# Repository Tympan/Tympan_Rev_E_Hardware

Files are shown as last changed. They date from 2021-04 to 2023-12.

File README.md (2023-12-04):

# Tympan Rev E Hardware Light
Repository for Tympan Rev E Light Electronics and case designs. This version of the Rev E is based on the Teensy 4.1 by PJRC and incorporates the Teensy 4.1 into our own design, as we did with the Tympan Rev D. This version is light in that it does not contain an on-board AIC, and is meant to be a PCB bridge between the Teensy 4.1 and the AIC Shield.

This is a work in progress.

## Check Back For Updates

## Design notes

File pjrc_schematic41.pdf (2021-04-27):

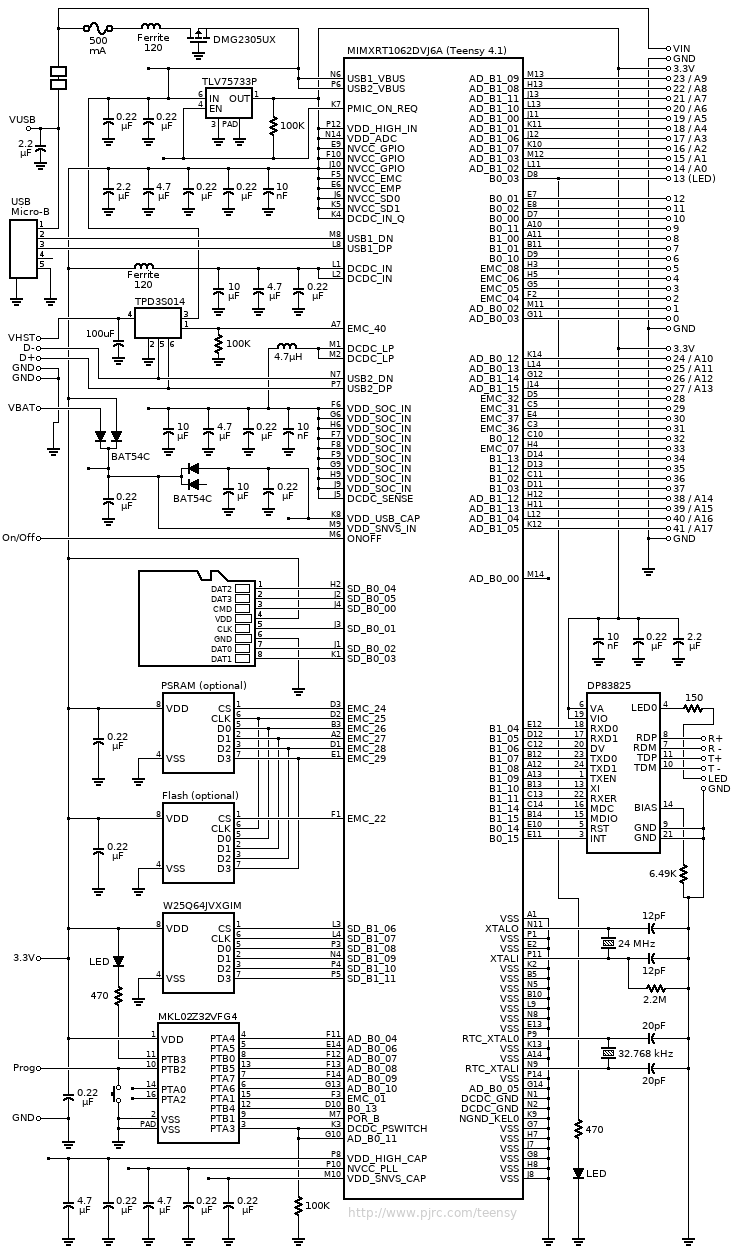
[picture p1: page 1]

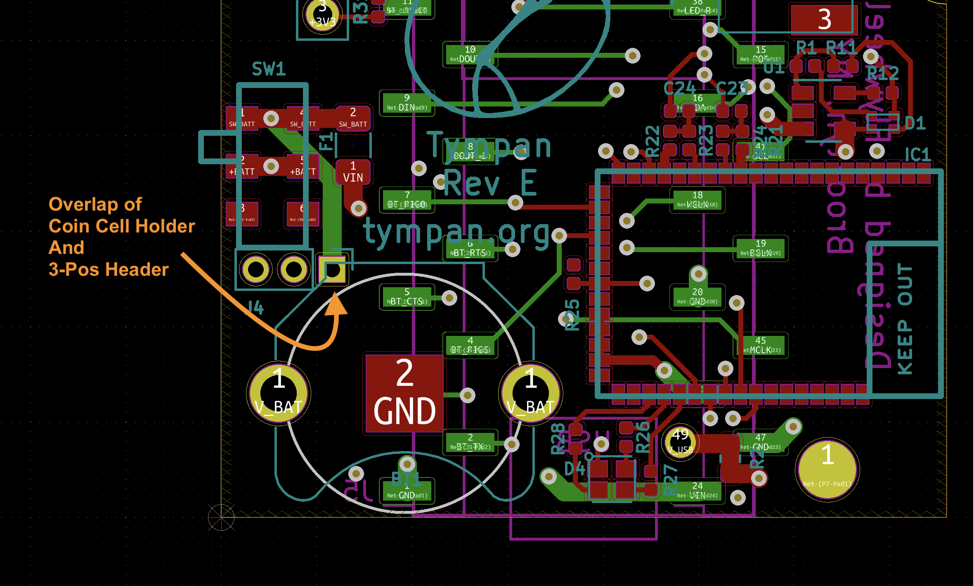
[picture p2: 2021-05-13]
assets/coin_cell_header_collision.png

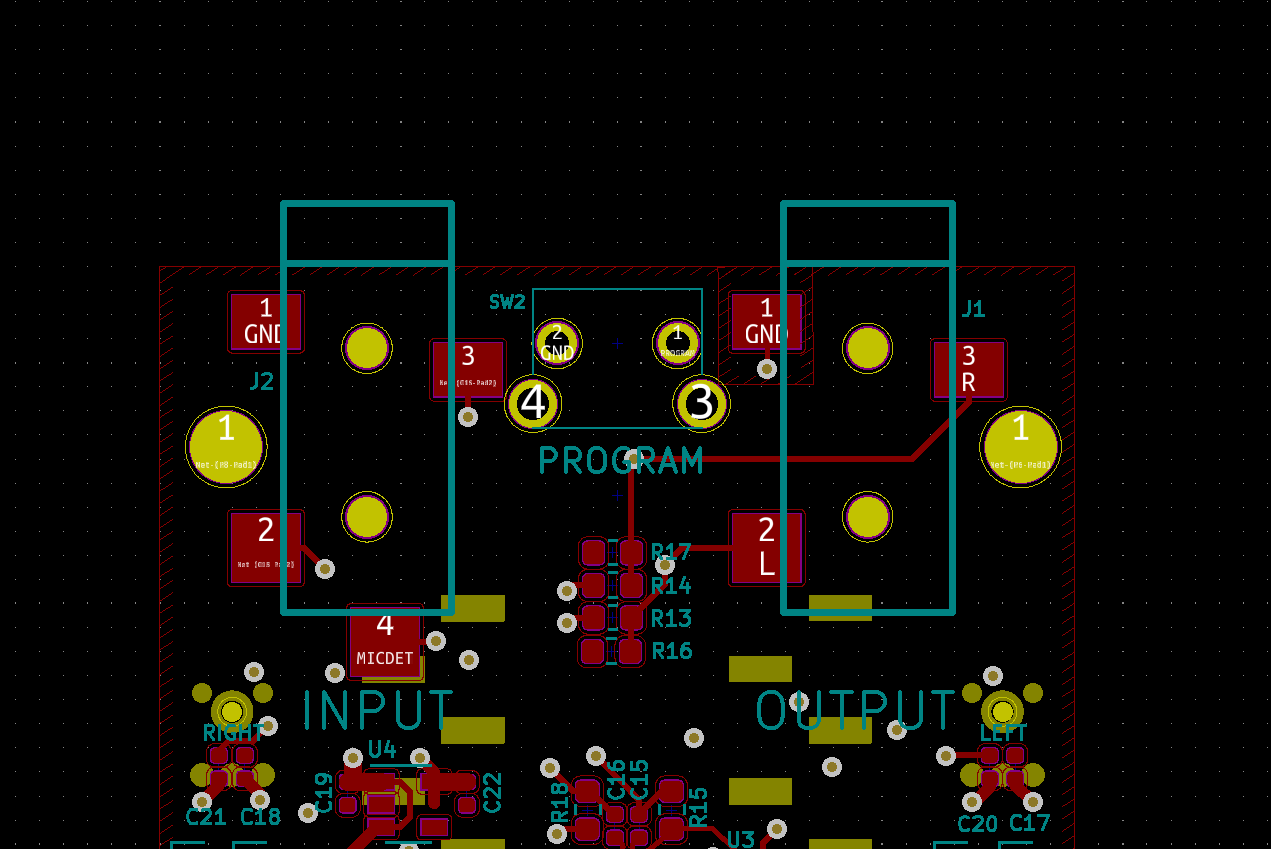
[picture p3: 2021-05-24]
assets/programButton.png

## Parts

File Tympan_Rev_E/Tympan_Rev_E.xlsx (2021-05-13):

Reference | Quantity | Value | Footprint
BT1 | 1 | Battery_Cell | Battery:BatteryHolder_Keystone_3001_1x12mm
BT2 | 1 | 4UCON-20519 | Solutions:4UCON-0217-20519
C7 C9 C14 | 3 | 10uF | Capacitor_SMD:C_0402_1005Metric
C1 C2 C3 C4 C5 C11 C15 C16 C23 C24 | 10 | 2.2uF | Capacitor_SMD:C_0402_1005Metric
C12 C19 C20 C21 C22 C26 | 6 | 1uF | Capacitor_SMD:C_0402_1005Metric
C6 C8 C10 C13 C17 C18 C25 | 7 | 0.1uF | Capacitor_SMD:C_0402_1005Metric
D1 | 1 | APHB1608SGNC | Tympan:ABHB1608S
D2 | 2 | LED AMBER | 1206
D3 |  | LED RED
D4 | 1 | Led_RGB_CA | Solutions:CLMVB-FKA-CFHEHLCBB7a363
F1 | 1 | FUSE | Capacitor_SMD:C_1206_3216Metric
IC1 | 1 | BC127 | Tympan:BC127
J1 | 1 | SJ-3523-SMT-TR | Tympan:SJ-3523-SMT-TR
J2 | 1 | SJ-3524-SMT-TR-PI | Tympan:SJ-3524-SMT-TR
J3 | 1 | Conn_01x03 | Connector_PinHeader_2.54mm:PinHeader_1x03_P2.54mm_Vertical
MIC1 MIC2 | 2 | SPM0687LR5H-1 | Tympan:SPM0687LR5H-1
P1 P2 P3 P4 | 4 | CONN_01X06 | Connector_PinHeader_2.54mm:PinHeader_1x06_P2.54mm_Vertical
R1 R11 R21 R22 | 4 | 1K | Resistor_SMD:R_0402_1005Metric
R12 | 1 | 2.2K | Resistor_SMD:R_0402_1005Metric
R13 R14 | 2 | 0R | Resistor_SMD:R_0603_1608Metric
R15 R18 | 2 | 2.2K | Resistor_SMD:R_0603_1608Metric
R19 R20 | 2 | 240R | Resistor_SMD:R_0402_1005Metric
R23 R24 R31 | 3 | 10K | Resistor_SMD:R_0402_1005Metric
R25 | 1 | 100K | Resistor_SMD:R_0402_1005Metric
R26 R27 R28 | 3 | 470R | Resistor_SMD:R_0402_1005Metric
R3 R4 R5 R6 R7 R8 R9 R10 | 8 | 33R | Resistor_SMD:R_0402_1005Metric
R29 R30 R32 R33 | 4 | 4K7 | Resistor_SMD:R_0402_1005Metric
RV1 | 1 | POT | Connector_PinHeader_2.54mm:PinHeader_1x03_P2.54mm_Vertical
SW1 | 1 | CL-SB-22A | Tympan:CL-SB-22A
U1 | 1 | MCP73831 | Package_TO_SOT_SMD:SOT-23-5
U2 | 1 | TLV320AIC3206IRSBT | Package_DFN_QFN:UQFN-40-1EP_5x5mm_P0.4mm_EP3.8x3.8mm
U3 | 1 | 74LVC1G66 | Package_TO_SOT_SMD:SOT-353_SC-70-5
U4 | 1 | LP5907MFX-1.8 | Package_TO_SOT_SMD:SOT-23-5
U6 | 1 | LC709203 | Tympan:WDFN8_3X4mm_0.65P

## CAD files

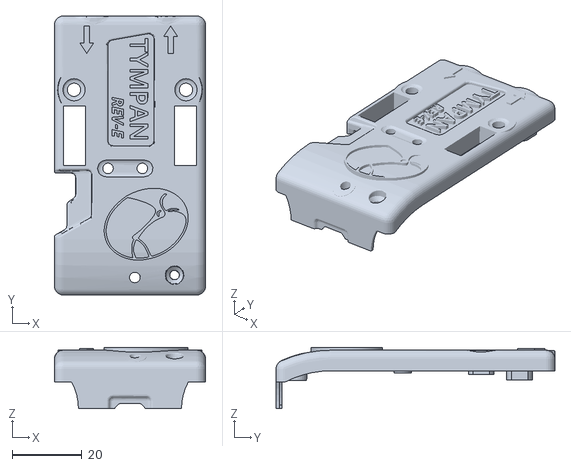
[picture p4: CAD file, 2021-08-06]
Enclosure/7-21 Tympan Rev E-2 Top.stl
43.2 x 79.8 x 17.5

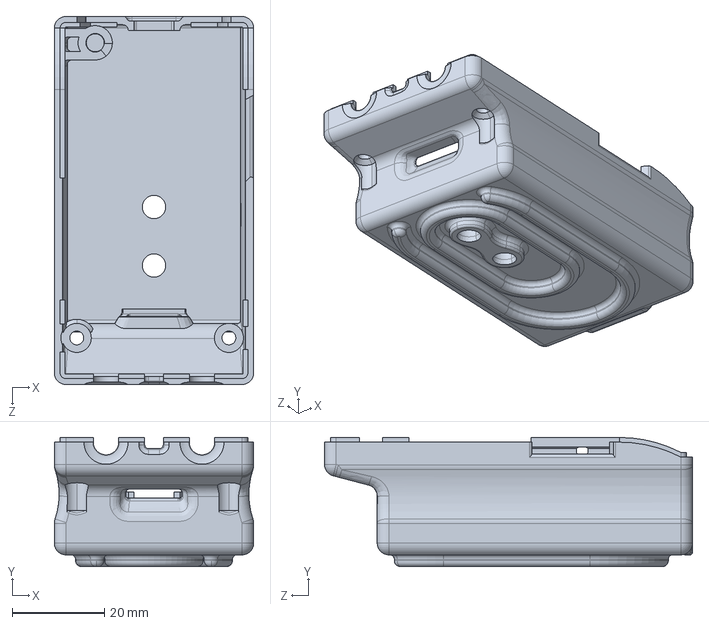
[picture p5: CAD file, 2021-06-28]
Enclosure/Exports/7146_Tympan_Rev-E2_Bottom_Case.STEP
43.2 x 28.0 x 79.8 mm

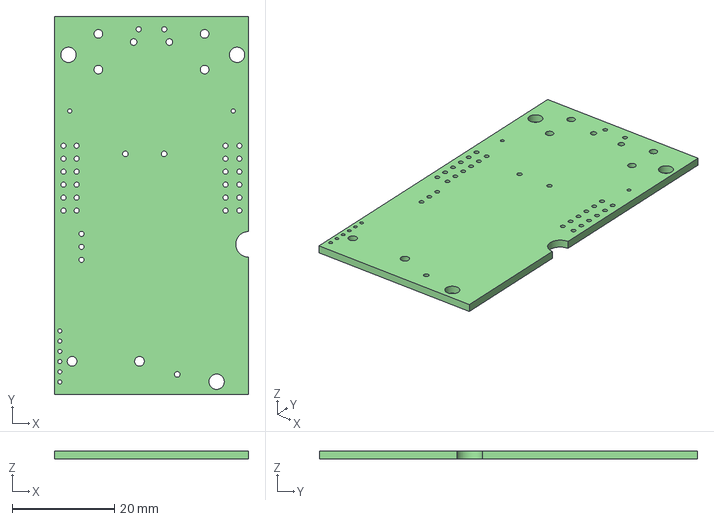
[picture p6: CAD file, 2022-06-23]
Tympan_Rev_E/Tympan_Rev_E.step
38.0 x 74.0 x 1.60 mm

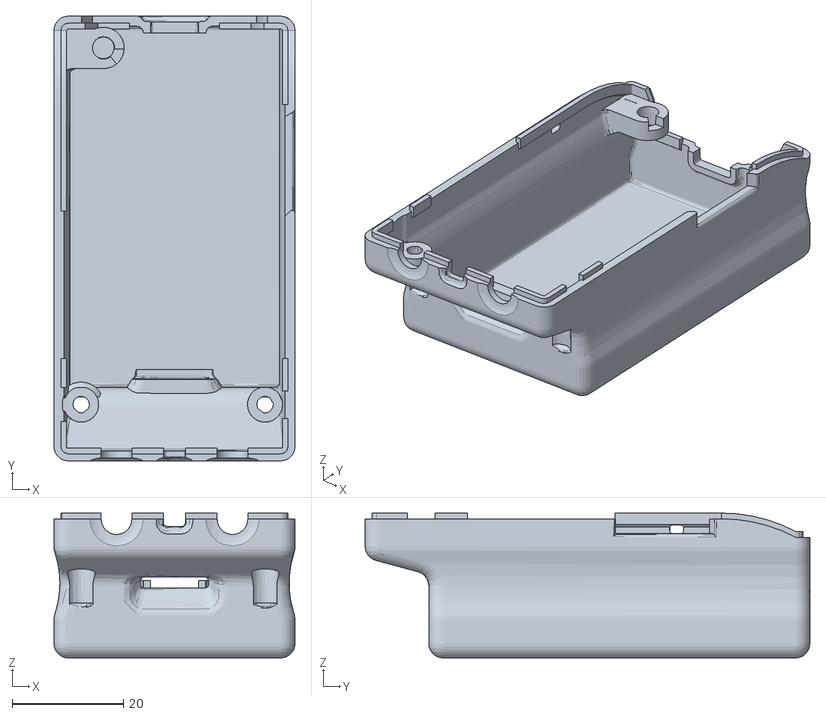
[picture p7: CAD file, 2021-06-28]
Enclosure/Exports/Tympan Rev E-2 BOTTOM_Flywheel_Mod.stl
43.2 x 79.8 x 26.0

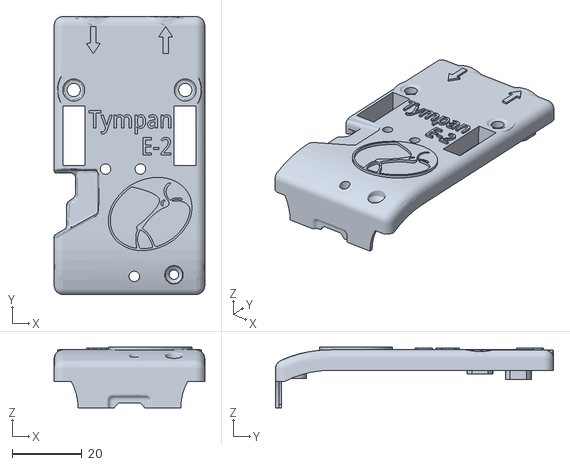
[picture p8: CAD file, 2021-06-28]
Enclosure/Exports/Tympan Rev E-2 TOP_Flywheel_Mod.stl
43.2 x 79.8 x 17.5

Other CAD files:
Enclosure/7-21 Tympan Rev E-2 Bottom.stl
Enclosure/Exports/7146_Tympan_Rev-E2_Top_Case.STEP
Enclosure/Exports/7146_Tympan_Rev-E2_Bottom_Case.stl
Enclosure/Exports/7146_Tympan_Rev-E2_Top_Case.stl

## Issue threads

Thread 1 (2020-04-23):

Identify all Teensy4 pins desired for I2S / Audio experiments

chipaudette, 2020-04-23:
There are several I2S buses on the Teensy4, each with their own clock and data pins.  Which of these pins should we break out and make available in the RevE hardware?

chipaudette, 2020-04-23:
@biomurph @erk1313

See, I do know how to use GitHub to make issues.  :)

chipaudette, 2020-04-23:
Apparently, they've done lots of development on multi-channel audio since I last checked.  They've got 8-channel I2S classes now.   It appears one can do up to 8-in / 2-out, or you can flip it around and get 2-in / 8-out.  That's pretty hot.

Here's one example, using 8 inputs.

https://github.com/PaulStoffregen/Audio/blob/master/examples/Analysis/PeakAndRMSMeter8Channel/PeakAndRMSMeter8Channel.ino

chipaudette, 2020-04-23:
Here are the forum links that I used as reference:

https://forum.pjrc.com/threads/57423-Teensy-4-0-I2S-without-Audio-Shield-and-flash-memory-question

https://forum.pjrc.com/threads/57167-Teensy-4-0-I2S-Support

https://forum.pjrc.com/threads/41371-Quad-channel-output-on-Teensy-3-6?p=230270#post230270

chipaudette, 2020-04-23:
OK, here are the I2S connections that are supported on the T4.

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

I'm not sure which get routed to the two AICs.  It looks like there can be several "right" answers, depending upon how the audio library software is configured.  Some experimentation will be needed.  This is why I'm hoping that the board provides some through-holes to allow me to jumper different Teensy pins to different I2S data lines to the Tympan's AIC and to the AIC shield.

chipaudette, 2020-04-23:
@biomurph, can you take a look at these pins and think about whether we can make all of them available to the hacker-user?

biomurph, 2020-04-23:
That'a great that the Teensy community pulled off 8 channel audio!
s u r r o u n d   s o u n d
I will look into what this means for the schematics that I already put together.

chipaudette, 2020-04-23:
FYI, in looking at the Teensy Audio Shield, it looks like the baseline 2-channel I2S pins are (not surprisingly) I2S Port #1 and employing Pins 7 and 8 for the actual data...so "OUT1A" and "IN1".  Fine.

Still looking at the Teensy Audio Shield, it looks like*
* The T4 Pin labeled "OUT1A" is actually **receiving** data from the audio shield
* The T4 Pin labeled "IN1" looks to be **sending** data to the audio shield

This is found purely by looking at Paul's diagrams and tables here: https://www.pjrc.com/store/teensy3_audio.html.  Perhaps I'm misinterpreting.

Why do they call it DIN/DOUT??? So confusing!  Why not MOSI and MISO??

biomurph, 2020-04-27:
I put up a spreadsheet with the Rev E pin assignments [here](https://docs.google.com/spreadsheets/d/1BYLmCkXKEUeF8b7aSnclLnglRlwAUCEZ10-2DhZgXo0/edit?usp=sharing).
Image of the spreadsheet below. I am able to fit in both of the I2S busses and only have to move a couple things around. Here are the moves and the potential issues

- Moved BT_CTS and BT_RTS. I assume these are software defined pins?
- Moved M_BIAS. This is software defined, so no problems there.

There's still a lot of flexibility for board layout and routing needs.

- The extra OUT1 pins are assigned to software defined functions in this draft, so they can be moved as needed
- I have not relocated the SPI bus pins, as this is a feature that we are not using so much.

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

chipaudette, 2020-04-27:
Regarding the BT_CTS and BT_RTS, I'm not sure that I've ever actually used these pins.  I'm not sure that I've ever used CTS and RTS (at least, not on-purpose) so I'm not even sure how to use them!

Looking in Tympan.h, where I define all the pins for the different versions of Tympan, the only BT pins that I see are:

'''
    BT_nReset = 34;  //PTE25, active LOW reset
    BT_REGEN = 31;  //must pull high to enable BC127
    BT_PIO0 = 56;   //hard reset for the BT module if HIGH at start.  Otherwise, outputs the connection state
    BT_PIO4 = 33;  //PTE24...actually it's BT_PIO5 ??? JM: YES, IT IS BT_PIO5!
'''

So, I guess that it's not a problem that BT_CTS and BT_RTS get moved.

Chip

chipaudette, 2020-04-27:
Regarding needing more I2C connections in order to feed all of my dreamed-about AICs, that's a good catch.  Seems like we'll need an I2C multiplexer.

https://www.adafruit.com/product/2717

Now it seems like this is kinda getting out of control, eh?  It seems like that if I want to do a proper 4-aic (ie 8 audio channel) demo, I really ought to design the board to do that, including all of the AICs.  I mean, with this RevE, what am I going to do...do flying leads off to all of the other AICs?!?  That sounds crazy.

So, maybe we should limit our scope with Rev E.  We should assume that we're going to talk with the on-board AIC the same way that Paul has the T4 talking to the Teensy Audio Shield (the new RevD version of the Teensy Audio shield).  It's the second Tympan AIC that I'm less sure about...

So, for the second Tympan AIC, we'll control it via the 2nd I2C bus, like with Tympan RevD.  The unknown is which I2S connections I want to route over to the headers for our shield.  So, I guess it's here that I need through holes for the various I2S lines that I specified above.  And then I need a few more through holes that let me mix-and-match those signals over to the headers that go up to the AIC shield.

Does that make sense?

Chip

chipaudette, 2020-04-27:
If we're super lucky, I might even be able to use my new T4.1 beta and do flying leads over to a pair of RevC boards.  Then, I could try Paul's example 4-channel code that has been extended for T4 (even though its documentation hasn't) and give it a try.  Through such a demonstration, I'd prove exactly which pins we want.

But, that'll take me a little time.  Tomorrow (being my "teleconference Tuesday")  is not going to be the day for that.

Chip

chipaudette, 2020-04-28:
After checking in on the forum regarding the I2S_quad class and its support for Teensy 4, I got the following response...

https://forum.pjrc.com/threads/58754-What-is-the-current-state-of-Audio-Library-support-for-the-Teensy-4-0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

So, maybe pins 6 and 8 for the two I2S input data lines (ie, data from the AICs to the Teensy) and maybe pins 7 and 32 for the two I2S output data lines (ie, data from the Teensy to the AICs).

I'm cross-referencing with the Teensy 4 pinout now...

Chip

chipaudette, 2020-04-28:
Looking at the [Teensy 4.0 pinout](https://www.pjrc.com/store/teensy40.html), specifically at the yellow colored pins flagged for "Digital Audio", I see:

Pin 6 = OUT1D
Pin 8 = IN1  (This is "DOUT" on the [Teensy Audio Shield RevD](https://www.pjrc.com/store/teensy3_audio.html))

Pin 7 = OUT1A  (This is "DIN" on the Teensy Audio Shield RevD)
Pin 32 (pad on bottom of T4) = OUT1B

So, the Pin 8 and Pin 7 are consistent with the Teensy Audio Shield (RevD), which is great.  In a quad setup, this suggests that these would be audio channels 1 and 2 (out of 4).  This suggests that the channels 3 and 4 would be on Pins 6 and 32.  If true, this would mean that the I2S_quad classes are exploiting the processor's ability to remap some of the I2S lines between inputs and outputs.  Cool.

With my beta Teensy 4.1, I should be able to prototype this using Teensy Audio Boards that I have on-hand.  I may get to try this tonight.

Chip
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
chipaudette, 2020-05-20:
Using this new test hardware....

I ran a quad-channel version of the tone sweep sketch.  It correctly generated audio out of the headphone jack on each of the two boards (independently).  So that's a success.  It proves that swapping pin 32 for pin 7 is the correct substitution.  Put that one in the bank.

However, when I try to acquire audio to bring in via the line-in / mic input, I can't get audio to come in via the 2nd audio board.  So, this calls into question the pin 6 for pin 7 swap.  In visually inspecting the modified board, however, I'm not sure that the mod was done correctly.  So, when I'm in the office again (Friday?), they'll take another cut at it.

chipaudette, 2020-05-28:
Under the assumption that we didn't modify the board as intended, we took a fresh Teensy Audio Board and did the modifications again.

Again, it can play audio out the headphone jack just fine, but it cannot record audio from the line-in jack.  :(

chipaudette, 2020-05-28:
I posted this issue to the Teensy forum:  https://forum.pjrc.com/threads/61123-Teensy-4-1-and-4-channel-audio-(AudioInputI2SQuad)?p=241457#post241457

biomurph, 2020-05-28:
I hope the power of the forum will come to our rescue!

Joel
~~~
Making the world safe for robots
www.biomurph.com

On Thu, May 28, 2020 at 4:23 PM Chip Audette <notifications@github.com>
wrote:

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

chipaudette, 2020-06-04:
The forum gave some debugging ideas.  And, Paul himself [jumped in](https://forum.pjrc.com/threads/61123-Teensy-4-1-and-4-channel-audio-(AudioInputI2SQuad)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) to demo that the system worked for him.

So, I brought the hardware back to the lab.  We probed pin6 and saw digital data.  Then, we disconnected our pin6 wire and did a flying lead direct to pin6.  The system worked.  Then we removed the flying lead and soldered our original wiring back in.  For some reason, it now works.

Conclusion: the Teensy4 support for quad audio works using pins 8+7 and pins 6+32.

I now have to decide what other pins, if any, I want broken out.

biomurph, 2020-06-04:
Sweet!
So those pins 8+7, 6+32 are the DIN DOUT pairs for coms with the AIC, correct?

chipaudette, 2020-06-17:
Yes, 8+7 is one set (the default set) and 6+32 is the second set (for the optional AIC).

As for which is DIN and which is DOUT, this is a long-standing problem of ours.  I'm looking at your google spreadsheet now.

chipaudette, 2020-06-17:
Looking at the RevD schematic, it looks like our "DIN" and "DOUT" are relative to the AIC.  So, in this convention:

* DIN for the 1st AIC = T3.6 Pin 22 = T4.x Pin 7
* DOUT for the 1st AIC = T3.6 Pin 13 = T4.x Pin 8

* DIN for the 2nd AIC = T3.6 Pin 15 = T4.x Pin 32
* DOUT for the 2nd AIC = T3.6 Pin 38 = T4.x Pin 6

I think that you've already accounted for the I2C and SPI signals moving pins on the T4.x vs the T3.6?

chipaudette, 2020-06-17:
Looking at your google spreadsheet a little bit, it looks like the Pin6 and Pin32 assignments will force you to move some of the existing functions.  Bummer, but we'll deal.  Hopefully there are pins that you can move them to!

chipaudette, 2020-06-17:
Is there more input that I need to provide here?

biomurph, 2020-06-18:
Thanks for chasing that down! I will see about re-juggling the pin assignments to fit the I2S and offer it up for review.

biomurph, 2020-08-03:
@chipaudette
Per your notes here, I have updated the schematics to reflect the correct DIN, DOUT, DIN_1, DOUT_1 pin connections.
The other pin connections that are flexible are in place and subject to change for ease of routing purposes.
Plan is to break out all of the unused pins, and also add the recommended memory chips on the bottom of the board.
Here's direct link to the [schematics](https://github.com/Tympan/Tympan_Rev_E_Hardware/blob/master/Tympan_Rev_E/Tympan_Rev_E_Schematic.pdf)
Couple of questions:

1. ON/OFF pin can be connected to a pull-down push button to manually turn off and then on the chip. Do we need it?

2. REV_TEST functionality. For Rev D, we used pin 44 tied to GND. Teensy 4.1 does not have a pin 44. I'm using pin 22 (no special reason). Should we connect 22 to GND as we did for rev D? Use another pin?

chipaudette, 2020-08-12:
I don't see a need for the "ON/OFF" button...but I'm not knowledgeable about it.  If there's not one on the T4.1, I guess that we don't need one.

For REV_TEST, using pin 22 seems fine enough to me.

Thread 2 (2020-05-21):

Increase capacity of the 3.3V power supply

chipaudette, 2020-05-21:
In my experience running 4 channels at high speed with SD writing, the system becomes unstable.  I believe that the power draw is too large for the existing regulator, given the voltage of the LiPo battery.

Recent current draw measurements suggest that we can pull 200-300 mA, which is nearing the max of the current [AP2210 regulator](https://www.diodes.com/assets/Datasheets/AP2210.pdf).  Specifically, if we were to pull 300 mA, the voltage drop would be 250-500 mV, which means that our battery would need to have a voltage of 3.55 to 3.85 V.  Given that the nominal voltage is 3.7V (though higher after immediate charge), that's a recipe for brown-out and for much reduced battery life.

Moving to the Teensy 4, where we can move to higher CPU speeds, we will likely increase this power consumption even more.  I think that we'll be regularly in the 300 mA range, with excursions higher.
 I think that we should consider bigger power supplies.

Looking at digikey, the nearest bigger regulator is the [AP2213, 500 mA](https://www.diodes.com/assets/Datasheets/AP2213.pdf).  What I see, however, is that the total capacity may be higher, but that the voltage drop is the same for a given current draw.  So, if our problem is that our battery voltage just isn't high enough for the regulator to deliver the required current, switching to the 2213 doesn't appear to solve the problem.

@biomurph, @eyuan-creare : does anyone know of a low-noise regulator (similar to the 2210) that has less voltage drop when in the 200-400 mA range?

biomurph, 2020-05-21:
I just did a quick look at Adafruit WiFi module ([HUZZAH ESP32](https://learn.adafruit.com/adafruit-huzzah32-esp32-feather/downloads?preview_token=0X3pzGCh9fm47-K5awpMrA) as those things are usually super power hungry and Adafruit is good at power supply design. They use the [AP2112](https://www.diodes.com/assets/Datasheets/AP2112.pdf), which has a high output current (600mA) and what seems like darn good drop out voltage. Not enough time right now to do a head-to-head comparison, but worth a look.

eyuan-creare, 2020-05-22:
Good thought Joel.  Never thought of looking at what other products use.  Here's a nice LDO, but it's expensive ($6).  Two package sizes:
[ADP7156ACPZ-3.3-R7](https://www.digikey.com/product-detail/en/analog-devices-inc/ADP7156ACPZ-3-3-R7/ADP7156ACPZ-3-3-R7CT-ND/5957834)
[ADP7156ARDZ-3.3-R7](https://www.digikey.com/product-detail/en/analog-devices-inc/ADP7156ARDZ-3-3-R7/ADP7156ARDZ-3-3-R7CT-ND/5957841)

Specs
* Dropout: 50-120mV
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

* PSSR: -80dB
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

eyuan-creare, 2020-05-22:
Noting the PSSR for the existing AP2210 regulator:
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

eyuan-creare, 2020-05-22:
If we are happy with 0.29V dropout, then there are some for $0.50 with 700mA output and low PSSR.
[NCP167 series](https://www.digikey.com/products/en/integrated-circuits-ics/pmic-voltage-regulators-linear/699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)

eyuan-creare, 2020-05-22:
AP2112 has a 0.25V dropout, which is nice.  PSSR is around 65dB:
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

And AP2213 only defines PSSR for 10mA, but it is around 60-70dB
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

 It has this note, which suggests that for good PSRR, Vin should be 1V higher than Vout.  Likely true for other LDOs as well.
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

eyuan-creare, 2020-05-22:
Nice reference on choosing LDO regulator specs from [Analog](https://www.analog.com/en/analog-dialogue/articles/understand-ldo-concepts.html)

eyuan-creare, 2020-05-26:
Alternatively, we could spec a buck boost converter for providing 5V to the BT module.  That would keep it from sagging the 3.3V bus when it sporadically draws current.

chipaudette, 2020-06-17:
Nice work, team!

For the AP2112, we have a working schematic from Adafruit and we have Adafruit's seal-of-approval.  That seals the deal for me.  Let's go with that.

chipaudette, 2020-07-06:
Adding a Buck-Boost option (as suggested earlier), for completeness.  Shouldn't be needed with a LiPo to support by 3.3V, but there is a certain appeal:

TPS6303x:  https://www.ti.com/lit/ds/symlink/tps63031.pdf

Let's stick with the AP2112 because of the adafruit documentation.

Chip

biomurph, 2020-08-03:
Moving to the Teensy 4.1 and reviving this topic.
The schematic for the 4.1 is [HERE](https://www.pjrc.com/teensy/schematic.html)
Paul is using the [TLV75733](https://www.ti.com/store/ti/en/p/product/?p=TLV75733PDRVR) Vreg.
The output current limit seems to be adequate. @eyuan-creare is the PSRR and drop out OK?

erk1313, 2020-08-03:
@Chip: @biomurph suggested the TLV75733, which is part of the Teensy 4.1 design.  It has a high output current (1A), a low dropout, and a decent PSSR.  The PSSR is less than our existing Rev-D regulator, but that's probably not important as we are not feeding it from a high-switching supply, nor have components that create high frequency noise.  I would say it's fine.

| IC | Max Current | Dropout @500mA | PSR @ 10kHz; 500mA | PSSR Plot |Link |
|----|----|----|----|----|----|
| AP2112 | 600mA | 250mV | 67dB |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|[datasheet](https://www.diodes.com/assets/Datasheets/AP2112.pdf)|
| TLV75733 | 1000mA | 175mV| 45dB | 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|[datasheet](https://www.ti.com/lit/ds/symlink/tlv757p.pdf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)

chipaudette, 2020-08-12:
Sounds good...let's go with the TLV75733.

Closed 2020-09-25.

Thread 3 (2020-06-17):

Design for T4.0 or T4.1?

chipaudette, 2020-06-17:
I believe that you had found solutions for the all those difficult-to-use pads on the T4.0, but why should we stick with the T4.0 form-factor when we could just switch to the T4.1 and use much-friendlier female 0.1" headers?

biomurph, 2020-06-18:
ooooooooh yeah!!
Life just got easier.

Looking at the specs, it is a nice beast! USB Host! Ethernet! Memory expansion!

I'm gonna get mine today!

biomurph, 2020-09-03:
@chipaudette I have the board laid out and routed.
It looks good to me, and I'd like to green light a prototype run.
Please take a look at the work and let me know what you think.

I have the Teensy mounted on the bottom of the board. Can do with mating headers, or can do by soldering SMT pins into the teensy 4.1 for low profile.

Same form factor as the Tympan Rev D, with breakouts, board size, mounting holes, volume knob, power switch, LEDs all in the same position (except for the charging LED...)
I plan to route a slot on the right of the board to allow the battery cable to snake to the back of the board.

biomurph, 2020-09-08:
@chipaudette
The board is ready to go! Please take a look at the schematics and let me know if you see anything that needs attention, otherwise I am prepared to green light this design and get the BOM ordered.

Closed 2021-06-10.

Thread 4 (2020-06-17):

Startup of BT Module

chipaudette, 2020-06-17:
@eyuan-creare and @biomurph ,

On RevD, we have the issue where sometimes the BT module doesn't start when the rest of the system starts.  The most obvious symptom is that the 3-color LED attached to the BT module never comes on.

We have talked about this.  But did we ever identify the specific circuit changes that we wanted to implement to try to make this problem better?  If so, we could try some here on Rev E.

Does anyone have any notes?

eyuan-creare, 2020-06-17:
Captured with the Rev-D issue: https://github.com/Tympan/Tympan_Rev_D_Hardware/issues/2
The BT Module datasheet provides an example circuit, I believe.  If not, let me know and I can dig up a blog post that went into more detail.

biomurph, 2020-06-18:
That RC circuit referenced is very easy to add.

A (maybe related) issue is one I've noticed, and would appreciate if someone could try to replicate it.
I'm attempting to turn the BC127 on and off by controlling the BT_nRESET (pin 34).
I'm using a pushbutton, but I'm sure that it could be toggled with a serial prompt.
The issue is that the BC127 does not always come out of reset when I try to turn it on. Maybe I'm holding the reset pin low for too long... It does wake up when I only reset for a short while (seconds) but if long(er) then it's no-go.
Maybe I'm doing it wrong, but my goal is to turn off the BT module when not in use, so that it will save power.

eyuan-creare, 2020-06-19:
Transferred the Rev-D issue to this repo.  Closing this so it is in one spot.  Refer to #5

Closed 2020-06-19.

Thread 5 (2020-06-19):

Intermittent power up fail on the BC127

biomurph, 2020-06-19:
Every so often at start up the BC127 LEDs don't flash, indicating that it has not booted up correctly. Since this is intermittent, it seems to be a result of the power supply. There is a related issue [here](https://forum.pjrc.com/threads/31688-chip-won-t-power-on-unless-I-wait-since-last-power-on). The recommendation from the BC127 datasheet is on page 26 of [this document](https://media.digikey.com/pdf/Data%20Sheets/Sierra%20Wireless%20PDFs/BC127_-HD_-EXT_TechSpec_4-9-17.pdf).

There's room on the board to add the RC circuit in the next hardware revision.

eyuan-creare, 2020-06-19:
Here is the boot sequence required by the BC127.  Note that VReg needs pulled high 5ms after VBat goes high.
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

[Datasheet](https://media.digikey.com/pdf/Data%20Sheets/Sierra%20Wireless%20PDFs/BC127_-HD_-EXT_TechSpec_4-9-17.pdf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)

Here is what the existing code does under Tympan.h.  I believe this sequence needs updated. I also recommend adding error checking, where the BT127 is reset if there is a problem (BT_nReset = LOW for >20ms).  @chipaudette let me know if you want me to start a feature branch to try this out.

@biomurph: The device should power on with BT_REGEN = LOW and BT_nRESET = HIGH.  Can you change the pull-down/up resistors so it starts this way?

**Existing boot sequence**
1. Upon setupPins(), set BT_REGEN = HIGH; wait 10ms
2. Set BT_REGEN = LOW
3. Set BT_nReset = LOW; wait 10ms
4. Set BT_nReset = HIGH
5. Configure BT_PIO0, as input

```
	//get the comm pins and setup the regen and reset pins
	USB_Serial = pins.getUSBSerial();
	BT_Serial = pins.getBTSerial();
	if (pins.BT_REGEN != NOT_A_FEATURE) {
		pinMode(pins.BT_REGEN,OUTPUT);digitalWrite(pins.BT_REGEN,HIGH); //pull high for normal operation
		delay(10);  digitalWrite(pins.BT_REGEN,LOW); //hold at least 5 msec, then return low

	}
	if (pins.BT_nReset != NOT_A_FEATURE) {
		pinMode(pins.BT_nReset,OUTPUT);
		digitalWrite(pins.BT_nReset,LOW);delay(10); //reset the device
		digitalWrite(pins.BT_nReset,HIGH);  //normal operation.
	}
	if (pins.BT_PIO0 != NOT_A_FEATURE) {
		pinMode(pins.BT_PIO0,INPUT);
	}

	forceBTtoDataMode(true);
```
As of commit:  b927b227a25902c28c43c8ed1745633a7fbc59a0

**Recommended boot sequence:**
1. Upon setupPins(), configure BT_REGEN as input with pull-down, and BT_nReset with pull-up (or just rely on the external resistors to do this);
2. Set BT_REGEN = LOW; set BT_nReset = HIGH
3. Wait 5ms; set BT_REGEN  = HIGH
4. Test communication to BC127.  If it fails set BT_nReset = LOW for >20ms, then begin boot process again.

eyuan-creare, 2020-06-19:
I would also recommend putting a scope on the BC127's VCHG during the boot up process.  Look for it to dip below 3.1V.  This pin is what initiates the boot sequence. This measurement will help set what the filter should be.   It should be easy to tack on their recommended RC and take a measurement.  This should be tested to see how low the V-Bus can go without causing a dip that restarts the BC127, during bootup and communication.  This will help inform whether the buck boost is sufficient and where we should set our brown out point (if that's incorporated into the next design).
@chipaudette : Let me know if you would like me to tackle this.

eyuan-creare, 2020-06-19:
Quick note... Attached is the most recent technical manual for the BC127
[41110693 AirPrime BC127 Product Technical Specification r2.pdf](https://github.com/Tympan/Tympan_Rev_E_Hardware/files/4805536/41110693.AirPrime.BC127.Product.Technical.Specification.r2.pdf)

Here are the reset conditions we are looking for.  Note: you can reset, or power down the BC127 depending on how long you hold it LOW.
```
The AirPrime BC127 can be reset intentionally by two methods:
· Hardware reset via RST# pin
· Reset—Pull the RST# low for > 5 ms to reset the module.
· **Power down—Pull RST# low for > 2.4 s** to power down. A rising edge on VCHG
or VREGEN is required to restart the module.
· Software reset via AT command—Send the AT command RESET over the UART
interface to reset the module.
```

biomurph, 2020-06-19:
@eyuan-creare
I have the VREGEN pin pulled low in the hardware.
BT_nRESET is not pulled anywhere.

I will try the  latest notes on toggling the VREGEN. Good to know that the thing will power down after 2 seconds! That's convenient!

I will also watch the VCHG and compare notes.

biomurph, 2020-09-08:
I have the reset pin for the BC127 pulled HIGH as per your suggestion.

eyuan-creare, 2021-01-22:
@biomurph Did we address this in the design of the Rev-E, or were you considering a change in the firmware?  I don't remember what we settled on for a course of action.

biomurph, 2021-01-23:
On the Rev E, I have the BT_nRESET (RST#) pulled up with a 10K.
The Rev D does not have this pullup installed.

Both Rev E and Rev D have pull down resistors on the VREGEN pins.
This should allow for the Rev E to power up with pins pulled in the right directions.
The Rev D, however, would need some software to manipulate the RST# pin correctly.3

eyuan-creare, 2021-01-23:
Great! I'll take a look at implementing the change in firmware.

eyuan-creare, 2021-08-03:
@chipaudette It looks like the boot sequence has been corrected. I think we can close this out.

The one caveat is that we are not filtering the power supply input to VCHG.  This is the kind of thing that could cause intermitted behavior.
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

--short version of existing firmware booting up the BC127--
https://github.com/Tympan/Tympan_Library/blob/0247190d9da8d58e457f77e4b671b1f5fa128797/src/Tympan.cpp#L41

```
(Note: BT_nRESET is pulled high)
pinMode(pins.BT_REGEN,OUTPUT);digitalWrite(pins.BT_REGEN, LOW);
delay(10);
digitalWrite(pins.BT_REGEN,HIGH); //pull high for normal operation

delay(100);
digitalWrite(pins.BT_REGEN,LOW); //then return low

pinMode(pins.BT_nReset,OUTPUT);
digitalWrite(pins.BT_nReset,LOW);

delay(50);
digitalWrite(pins.BT_nReset,HIGH);  //normal operation.
```

eyuan-creare, 2021-08-03:
@chipaudette Perhaps I stumbled on something...

VREGEN not only is critical in the boot process, but it is used to put the BC127 in discoverable mode.  In the current firmware, VREGEN is pulled high for 10ms to put in indiscoverable mode.  However, Melody 7 states that a "short" press is 50ms, whereas we only pull it high for 10ms.  Also, we pull the nRESET pin low then high after this short press of VREGEN.  So perhaps this timing is preventing the BT module from being placed in discoverable mode?

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

 In a previous Tympan commit, VREGEN is brought high for 10ms then brought low.
```
if (pins.BT_REGEN != NOT_A_FEATURE) {
		pinMode(pins.BT_REGEN,OUTPUT);digitalWrite(pins.BT_REGEN,HIGH); //pull high for normal operation
		delay(10);  digitalWrite(pins.BT_REGEN,LOW); //hold at least 5 msec, then return low
```

eyuan-creare, 2021-08-03:
@chipaudette Also note the difference between Melody 7(above) and Melody 5 (below).  The duration for a short press changed from <999ms to 50ms (probably to provide debouncing as their dev board uses a momentary switch).   Also, note that a long press has a different function.

[_Melody 5.0 Rev-D_
](https://cdn.sparkfun.com/datasheets/Wireless/Bluetooth/Melody_5.0_Manual-RevD-RC10-Release.pdf)

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

eyuan-creare, 2021-08-03:
@chipaudette: so while the Medody5 boots up as a discoverable device (under default settings)...
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

-----
Melody 7 states that it is **not discoverable on bootup.**
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

chipaudette, 2021-08-03:
@eyuan-creare  thanks for the additional research on the startup process and on the GPIO.

Two observations that would be helpful for you to comment on:

* The word "discoverable" is only meaningful for making BT Classic connections, not BLE.  In your discussion of short vs long pulses and their effect on the discoverable mode, do you expect it to affect my BLE problems or only the BT classic (ie BT Audio) problems?

* For the short/long pulse discussion, the module has two GPIO control modes: (1) GPIO control "on" and (2) the badly-named GPIO control "off".  [In truth, both modes still respond to the GPIO pins, they just respond in different ways.]  Do your comments have to do with mode "on" or mode "off" or is it some GPIO mode specific to just the startup process?

Chip

chipaudette, 2021-08-17:
@eyuan-creare In your comments above, you suggested that we have VREGEN be held low instead of our previous pattern of holding it high.  I've now explored this.

On RevE with V7.3 HD firmware, I switched the code to keep holding the pin HIGH.  There's no obvious difference in behavior either way.  I command BT Classic behavior ("connectable" and "discoverable") through direct serial commands, as you suggested.  The system seems fine...but, again, it's not obviously better either way.  My conclusion: Whenever V7 firmware is specified, I have Tympan.h hold the pin HIGH forever, per your recommendation.

On RevD with V5.5 firmware, when I switched the code to keep holding VREGEN high, the module shuts off after ~2 seconds.  Obviously, this is bad.  My conclusion: Whenever V5 firmware is specified, I have Tympan.h return to the original behavior of staying HIGH for 100 msec and then switching LOW and staying LOW forever.

eyuan-creare, 2021-08-18:
>>On RevD with V5.5 firmware, when I switched the code to keep holding VREGEN high, >>the module shuts off after ~2 seconds.

Yes that is expected behavior.  It is supposed to SET CLASSIC_ROLE=1, SET AUTOCONN=1, then reset.  I assume those are non-volatile and when it boots up again it should be held high.  We might want to revert a Tympan to default settings if we think a  "new" Tympan might act differently.

Otherwise I can close this out.  The last remaining question is  whether there is noise on the VBAT or VCHG supply lines that could cause an issue during startup.

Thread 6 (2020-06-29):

Add ability to disconnect the battery for shipping

eyuan-creare, 2020-06-29:
For federal regulations for shipping lithium batteries, refer to [49 CFR 173.185(e)](https://www.phmsa.dot.gov/lithiumbatteries).  Also look into regulations from UPS and FedEx.

* Here is a [reference design for shipping Li-Ion batteries from TI](https://www.ti.com/lit/an/slva821/slva821.pdf?ts=1593441515767) based on a momentary push button and a load switch:
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.  It is also mentioned [here](https://e2e.ti.com/blogs_/archives/b/fullycharged/archive/2016/12/27/don-t-let-your-battery-drain-on-the-shelf-use-ship-mode).

* Some charger ICs also have ship mode, such as the [LTC4071 ](https://www.analog.com/media/en/technical-documentation/product-selector-card/2PB_4071.pdf).  This IC disconnects the battery when VBat drops below a threshold voltage.  (This provides the added benefit of handling brownouts.)

* A battery management IC ([PF1550](https://www.nxp.com/docs/en/data-sheet/PF1550.pdf)) that enters ship mode via I2C, and exits ship mode when a charging voltage is present

* Another battery charger with ship mode ([STBC02](https://www.st.com/resource/en/datasheet/stbc02.pdf))

* Another charger with ship mode: [DA9070](https://www.dialog-semiconductor.com/sites/default/files/da9070_final_datasheet.pdf).  This can enter ship mode via I2C (delaying the battery disconnect until after power if removed).  Exits ship mode when input power is restored.

* Another charger with ship mode [ISL9241](https://www.renesas.com/us/en/doc/datasheet/isl9241.pdf): Enter ship mode via register.  Exit ship mode by connecting power.

eyuan-creare, 2020-06-29:
* If the battery was a button-top, then you could insert a small strip of plastic as the disconnect.
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

eyuan-creare, 2020-06-29:
@chipaudette We could either replace the battery charger IC or add a load switch with ship mode.  Ideally, the design would not require a momentary on/off button.

If you like these option, I can mock up a design to pass by Ray.  I like the fact that there are reference designs we can point to.

biomurph, 2020-08-03:
@eyuan-creare I"m not sure if we need this kind of feature. We ship with a low capacity LiPo (500mAh) and I have found that if you are shipping them contained in equipment. Check out the end of page 4 on this [doc](https://www.ups.com/assets/resources/media/en_US/pack_ship_batteries.pdf). I don't think that we need to worry about Tympan due to the small battery size. Once you get into bigger battery capacity, that's when there may be question, but it seems the cutoff is pretty clear.

(unsure why I'm just seeing this, will check my settings)

erk1313, 2020-08-03:
@biomurph There's a whole range of regulations for shipping Li-ion batteries.  I have a summary I can share at some later point.
 If it weren't for the fact that we qualify as a low-production prototype, we would require UN38.1 testing for the completed assembly.  I'll be reviewing how Creare interprets these regulations with Creare's safety person in August and will check back then.  Their initial ruling was that a physical disconnect was required, but I think that is too conservative a ruling.

biomurph, 2020-08-03:
Sounds good, @eyuan-creare
My research has only gone as deep as UPS and DHL.

eyuan-creare, 2020-09-08:
After a review by Creare's safety team, the Rev-D design was deemed safe for shipping with the battery connected, with these three design changes:
* Place the fuse immediately after the battery
* Move the power switch before the voltage regulators

Notes contained on networked folder: \\OLYMPUS\Projects\7146-Cool-Aid\Technical Work\Design\2020-0710_Shipping Lithium Batteries

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

biomurph, 2020-09-08:
@erk1313
I can make those changes to the Rev E prototype design.

chipaudette, 2020-09-25:
@biomurph
Was this change fully implemented in Rev E?

Looking at the current RevE schem, I think that I see that the switch has been moved, but I don't think that the fuze is as early in the circuit as is shown here in the figure above.  It's immediately after the battery in the figure above, but it appears to be after the switch in the current RevE schem...

biomurph, 2020-09-29:
@chipaudette Changes done on my local. Will push to repo.

biomurph, 2020-09-29:
Just for the sake of clarity on this. The resoning we had in the beginning to arrange the power supply this way was to make sure that the RTC [V-BAT] was powered by the 3.3V. We gave users the option to add their own external power for the V-BAT. In order to do this, when the Tympan D was 'off', there was power going to the RTC only, so the 3.3V reg was running to do that when the switch was 'off'. In this new version, we are adding a coin cell to power the RTC, so we don't need to run the LiPo to do that work. That's why in previous the switch was after the Vreg.

Closed 2020-09-29.

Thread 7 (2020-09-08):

Fuel Gauge for Battery Level

eyuan-creare, 2020-09-08:
Add a fuel gauge (or spec a charging IC with that feature) to report the estimated battery level of the device.  This will allow the Tympan to close an SD recording before a power failure.  Note that Lithium batteries cannot rely on voltage to determine charge level.

@chipaudette : is this a nice-to-have feature or a must?

biomurph, 2020-09-09:
Here is a candidate for fuel gauge
https://www.mouser.com/datasheet/2/308/LC709203F_D-1810548.pdf

eyuan-creare, 2020-09-09:
Thanks for checking into these.  I've never used one of these chips before.  I see that it uses a special technique that doesn't use a sense resistor, but it looks like it relies on a thermistor.  Are there other reliable methods of measuring battery capacity?  I simply ask because it adds another component to the battery.
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

chipaudette, 2020-09-09:
Did we really talk about doing this for Rev E, or is it for the MIT hardware?

chipaudette, 2020-09-09:
@biomurph, that's the same IC as used in the recently-advertised Adafruit board, right?

https://www.adafruit.com/product/4712

eyuan-creare, 2020-09-09:
Looks like Adafruit is using it without a thermistor, so they forgo temperature compensation.

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

@chipaudette Yes, we talked about it in the context of the Dosimeter.  We can shelve this if not needed.

biomurph, 2020-09-09:
@chipaudette Yes! it does look like Adafruit is using the same IC!
Funny, I did not even check to see if there was one broken out by the SparkFruit people.

@eyuan-creare I selected the LC709203 because it does not require an external current sense resistor, and also noticed that it can be used with or without thermistor temperature measurement.
It seems to be the easiest to implement, and since we are not doing anything that is high current, or really stressing the battery in any way, I thought that the temperature measurement would be optional. Do you guys feel that it is something that we should look into?

If you're interested in playing around with this IC in the Tympan Library, I can add it into the Tympan Rev D spec and we can drive it around a bit?

chipaudette, 2020-09-25:
I'm interested in this, but I'm more interested in getting Rev E built for the first time.  So, let's not do this (yet) for Rev E.

biomurph, 2020-09-29:
@chipaudette There is room for it, and I can route it in but leave it unpopulated for now. How does that sound?

biomurph, 2020-09-29:
I added it into the layout, and we can decide to populate it or not. Super easy.

Closed 2020-09-29.

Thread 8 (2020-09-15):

Typo in project description

justinclift, 2020-09-15:
Noticed a cut-n-paste typo in the project description, and figured it's probably useful to mention:

```
Repository for Tympan Rev D Electronics and case designs
```

"Rev D" → "Rev E"

:wink:

chipaudette, 2020-09-25:
Looks like it's been fixed!  Thanks!

justinclift, 2020-09-25:
Looking at the project description again just now... er... it's still saying "Rev D"?

Can screenshot it, if we're looking at different pieces and confusing each other. :grin:

Closed 2020-09-25.

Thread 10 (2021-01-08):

Bring Teensy USB signal up to Tympan (for power and programming)

eyuan-creare, 2021-01-08:
To expose the SD card slot in the enclosure, one _possibility_ is sliding the Teensy forward. However this would hide the micro USB port.  Depending on complexity, we may want to bring up the USB signal to the Tympan to relocate a port there.  On the plus side, this would allow us to use a USB-C connector.

Here’s the pins labeled D- D+ on the side opposite of the Teensy 4.1.  I outlined the traces on that side of the board.

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

I flipped that trace to match it up with the other side.  That should correspond to the fingers on the micro USB connectors: D- (2) and D+ (3).  I'll pint this out when I get my hands on a Teensy 4.1 today.

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

@biomurph, @chipaudette  Got any ideas for how we could bring the USB signal up?  Looks like it is 0.1" spacing.  Would a header fit these pads?

eyuan-creare, 2021-01-14:
I tried soldering a header (0.1in pitch) to the USB D+ D- pads, but failed and lifted up a pad.  If the Teensy is first soldered to the Tympan, then perhaps there's low risk of lifting the pad.

@biomurph What are your thoughts?  Do you think soldering a header to these pads is feasible, or would you suggest wire leads?
- We could also do pogo pins (if their height was short).  They would likely be fine under vibration, as their spring force can be rather high.  But there is a possibility of corrosion over time.

biomurph, 2021-01-14:
It looks like the solder pads are 0.1" spacing?
If so, that makes it easier to cope with.
Then the issue becomes finding room to mount the USB C...

What about using Occam's USB converter?
https://www.wish.com/product/5e1e787f93907f0566eb2d2d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
Might this be long enough to make the distance?

eyuan-creare, 2021-01-14:
@biomurph The adapter is a great idea and converts it to USB-C.   I'm a little sketched out by using an extension, but that may be less sketchy than adding headers/pogo pin/leads to the USB pads.  They are 0.1" spacing.  Would you like to try experimenting on one of the Teensy's you have designated for us?  Even if you lift the pad, it shouldn't effect the USB connection.  I think that pad is just a test point for them to program the device (just a guess).

I'll order that Amazon adapter in and take a look at how rigidly it is held.

biomurph, 2021-01-14:
@eyuan-creare I will take a look at it. I am hesitant to use pogo pins, as they present their own mechanical issues, but they may be the best answer if we do our own connector. I can see that it will be difficult to get the solder points done in situ with the boards so close together and the USB C mounted likely right near there, so I would think that the pogos, if they are available at the right length, might be our best bet.

I'm looking at the layout and there seems to be room to put SMT pads or maybe through holes in the area where they might need to land.

Another issue with 'sliding the teensy' is that the pads for the Teensy may be crashing against the audio jack mechanical mount holes??

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

eyuan-creare, 2021-04-12:
The USB extension looks a little sketchy.  Too much leverage to pop the USB connector off.<br>
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

eyuan-creare, 2021-04-14:
@biomurph: Chip thinks the risks of either approach outweigh the benefits of exposing the SD card.  Let's abort this request.

Closed 2021-04-14.

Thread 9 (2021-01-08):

Bring Teensy reset button up to the Tympan

eyuan-creare, 2021-01-08:
In the existing enclosure, the battery obscures the reset button.  If we brought the reset signal up to the Tympan, then we could place a second reset button in a better location.  Likely, this would be a "side-press" button, but that is TBD.

- Existing enclosure:

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

- Teensy 4.1 Schematic showing the PROGO trace from the reset button:
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

- Teensy 4.1 PCB showing the trace from the PROGO pin to the Reset Button.  @chipaudette confirmed that this thru hole pin transitions LOW when the reset button is pressed

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

eyuan-creare, 2021-01-08:
@biomurph looked into where the pin would fall:

Here is about the location of the pad that we would need to place for it.
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

The good news is that the pad for the pin next to it (pin 30) is not in the way.
Also, there's enough room to either place a thru-hole, with a bunch of parts/trace juggling, or placement of a single SMT pad, with less parts/trace juggling.

There's also the option of flying a lead from the T 4.1 to the Tympan..

eyuan-creare, 2021-05-17:
@biomurph suggested placing a momentary pushbutton (TL6340AF160Q) between the audio jacks:

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

This should work fine, though it is a tiny switch.  The button is 1/32" tall. @chipaudette if you fine using a paper clip, I can put a guide hole in.  If you would like a feature on the case with a cantilevered tab, then we should go bigger.

biomurph, 2021-05-17:
possible candidate switches
https://www.mouser.com/datasheet/2/910/909_2894_2893_DTSA-6-1571568.pdf
The DTSA-6 drawing will fit and it is a decent size. There are tons of them.

eyuan-creare, 2021-05-17:
Goldilocks says... that switch is just too big!  It does fit, within the height of the stock headers but let me see it there is an alternative.

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

eyuan-creare, 2021-05-17:
@biomurph What do you think of this switch? (faked up CAD model).  It still feels a bit big but there is not much out there for RA switches.
- APEM MJTP1117 ($.48 [Digikey](https://www.digikey.com/en/products/detail/apem-inc/MJTP1117/1795496)) SPST- NO
<br>
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
<br>
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

biomurph, 2021-05-17:
Works great! Im down to use it.
You have it overhanging the edge of the PCB. Is that how you want to?

eyuan-creare, 2021-05-17:
@biomurph yes, please have the button overhang. Thanks!

biomurph, 2021-05-21:
I placed the MJTP-117 push button between the audio jacks

chipaudette, 2021-06-10:
@eyuan-creare , is this done?  can we close this?

Closed 2021-06-10.

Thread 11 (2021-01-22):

Data/Clock Labels for PDM Mic are switched on the board and schematic

eyuan-creare, 2021-01-22:
Please refer to Tympan Rev-D issue and confirm that this applies to the Rev-E as well: https://github.com/Tympan/Tympan_Rev_D_Hardware/issues/5

biomurph, 2021-01-23:
Confirmed that this issue did persist from Rev D to Rev E.
Made the changes and pushed to fix this issue.

Closed 2021-01-23.

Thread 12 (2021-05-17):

Add Thru Holes for Reuse of GPIO lines to RGB LED

eyuan-creare, 2021-05-17:
@biomurph : *if there is space*, it would be nice to break out the GPIO going to the RGB LED.  I'm thinking (3) thru holes spaced 0.1in apart. But only if you have space.

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

biomurph, 2021-05-17:
I will see. What is the reason for this breakout?

eyuan-creare, 2021-05-17:
For additional I/O.  It's not critical but if you have space for it, we've run out of GPIO in the past when we are using up the available pins for I2C, PDM, etc...

biomurph, 2021-05-17:
Ah, those pins come from the BC127. If you want more Teensy pins, that's a different thing

eyuan-creare, 2021-05-18:
Ah.  You're right.  I'm glad you asked about the why.  Well, if there is room to put 2-pin thru holes next to LED_A & LED_R, that would work as well.  And if not, we'll close this.

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

biomurph, 2021-05-18:
I put in two breakout GPIOs on the 2mm header at the bottom left.

Pin 34 and 35 are also UART 8 TX and RX

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

eyuan-creare, 2021-05-18:
Thanks for correcting me.  For some reason, thought we were using 0.1in spacing.

biomurph, 2021-05-18:
Well, we are using 0.1" for the breakout headers that the shield plugs into. the 2mm header was what would fit to make the RTC battery power on Rev D. That 2mm header row has now grown a few pins.

eyuan-creare, 2021-05-18:
Ah.. now I understand.

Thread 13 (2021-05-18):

Size RTC battery

eyuan-creare, 2021-05-18:
The RTC on the Teensy4.1 is integrated on the micro, which the datasheet says requires (20uA).
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

However the Teensy 3.6 was measured to draw 2uA, while the datasheet suggests 1uA.  Paul believed this additional current was diode leakage, so let's assume 21uA for the Teensy 4.1:
https://forum.pjrc.com/threads/45399-Shutdown-RTC-current

The existing [CR1220](https://www.digikey.com/en/products/detail/panasonic-bsg/CR1220/269740) is 35mAH, which provides a life expectancy of 66days:
- 35mA-hr*3V/3.3V*20uA*1day/24hr = 66 days

Not very impressive.  But I believe this would only be the case if the main lithium battery was depleted.

~~~
We could go down to two 6mm coin cells (2*1.5V * 20mAh), but there were no holders for two stacked 6mm coin cells.

eyuan-creare, 2021-05-18:
@chipaudette Reducing the coin cell appears to be a dead end.  I have not measured actual Teensy 4.1 current draw, but from the spec sheet, the CR1220 should last ~66days.

Closed 2021-05-18.

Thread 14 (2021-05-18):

Room for QUIIC?

chipaudette, 2021-05-18:
@biomurph There's no room for a QUIIC connector anywhere is there?  (I do love QUIIC)

biomurph, 2021-05-19:
It looks like a Qiic connector could fit under the volume knob... lousy location...
Mayby I could throw one in above MIC1 next to the speaker jack?

biomurph, 2021-05-19:
Here's a shot of the Qwiic location that is the easiest to do.
It's at the front of the board, on the bottom layer, underneath the PROGRAM pushbutton between the audio jacks.

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

biomurph, 2021-05-21:
Placec Qwiic connector on the bottom near the battery connector. It fits!

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

Closed 2021-06-10.

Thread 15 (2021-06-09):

Decide Direction for the Rev-E Enclosure

eyuan-creare, 2021-06-09:
- [x] Determine what the stackup height is.  @biomurph is planning to solder the Teensy to the Tympan
- [x]  How do users access the SD slot?

_Here is the existing enclosure for the Rev-E with AIC shield_
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

- [ ] What plastic do we use?  The white plastic from Rev-D has shown yellowing under UV light

- [ ] Consider which screws we choose (such as plastite screws).

- [ ] Provide access to the reset button

biomurph, 2021-06-10:
@eyuan-creare do we need the belt clip? Do you have a part number for it?
I'm thinking it would be loose in the bag for users to apply if they want. So it could still rest on the table-top.

eyuan-creare, 2021-06-10:
@biomurph it's a bit pricey for what it is: [BELTCLIP MCS-661BP](https://www.theclip.com/store/metal-belt-clip-661).

I'll upload the CAD for the triple stack design that has the whole assembly.  What SW version are you working with?

biomurph, 2021-06-10:
Here's one that is a bit cheaper.
[belt clip](https://www.amazon.com/PSCCO-552510mm-Holster-Sheath-Spring/dp/B08NWSWCXG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) but it has a different shape for the mount surface...

I use FreeCAD. I don't do much with it. I'm not a versatile CAD user.
I also use TinkerCAD, which I find useful for making small changes and simple forms.

eyuan-creare, 2021-06-11:
@biomurph I like the idea of designing it so that anyone can print it with PLA.  Is there a UV protecting finish you could apply?

biomurph, 2021-06-11:
I will look into uv safe filament.
Would be better not to do a coating. That sounds messy.

Yes, the wan Shun models are good. I reworked them in tinkercad to make them print better on my machine

eyuan-creare, 2021-06-11:
Oooo..  Can you share any photos of your printed earpieces?  What wall thickness can you do?

biomurph, 2021-06-11:
Oh, I'm sorry I misunderstood.
I'm not talking about the earpieces I'm talking about the Rev D enclosure.

I have not printed the earpieces. Not worth it, since I figure the resolution will not come out well enough to use.

eyuan-creare, 2021-06-11:
- Go with (7) design from the SD Card issue #18 using Adafruit 2000mAh Li-poly battery
- Consider sliding case and front-screwed bottom
- Consider leaving extra height for battery (so no accidental reset button presses) and accommodate other batteries
- Leave holes for PCB mic (with funnel shape), LEDS (GPIO, BT, Charging)
- Consider "ASA Special Edition" embossing
- Note that Joel's printer can do 0.080" down to 0.040".  Joel to look into UV stable filament
- Aim for cases to be complete before June 21
- New changes to PCB include the reset button and Quic connector

biomurph, 2021-06-12:
Here's a shot of a prototype Dosimeter case print. Think it was done with a fast setting (lower resolution). I'm going to find a similar blue to the one you have
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

biomurph, 2021-06-12:
Here's the blue that I'm getting to work the prototypes and first cases with
https://www.matterhackers.com/store/l/pro-series-pla/sk/MFEFY96W

eyuan-creare, 2021-06-16:
### Change to Tympan Rev-E.2 PCB that affect enclosure
- Reset button added to **bottom** of Tympan between mic jacks
- Added Quiic connector
- @biomurph The model exported from KiCAD shows male headers.  Is this correct? Or are we using the same headers as the Tympan Rev-D?
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

biomurph, 2021-06-16:
Your changes should reflect that

1. The Rest Button is added to the TOP of the Tympan between the mic jacks
2. Added quick connector on the BOTTOM near the rout for the battery wire
3. That 3 pin header connector is actually the dial pot

Please see photos below from Circuit Hub

[Final Assembly Top](https://circuithub-static1.s3.amazonaws.com/orders/9547/attachments/lNMwFSlRScOHXfjlztSQ_IMG_20210615_201836.jpg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)

[Final Assembly Bottom](https://circuithub-static1.s3.amazonaws.com/orders/9547/attachments/zcIaBg9SregnpMCFA7E1_IMG_20210615_201904.jpg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)

eyuan-creare, 2021-06-16:
@biomurph What is the standoff between the Tympan and Teensy?  I show a gap of 0.150in.

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

eyuan-creare, 2021-06-16:
Also, which part are you using for the Quiic connector?

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

biomurph, 2021-06-16:
I think that the Qwiic connector might have miss hit the BOM in our repo.
It is listed in the [Circuit Hub Part List](https://circuithub.com/projects/biomurph/Tympan_Rev_E/revisions/35488/parts)
in this case, it is a [SparkFun](https://www.mouser.com/ProductDetail/SparkFun/PRT-16766?qs=TiOZkKH1s2S5E8Ch5jqJTg%3D%3D) part sold by Mouser.

I can confirm your measurement of 0.155" +/- 0.008" tolerance is enough wiggle room.

eyuan-creare, 2021-06-17:
Thanks.  I was able to source CAD for those two parts.  The Sparkfun Quiic connector is actually JST BM04B-SRSS-TB.

@biomurph Can you take a quick look to confirm I have all the important components on board?<br>
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

biomurph, 2021-06-17:
Stand by

biomurph, 2021-06-17:
On the bottom, you have the Qwiic connector in the wrong orientation.
It should be a Right Angle part. With the opening toward the edge of the board.
Here are the production photos. Those links above don't work

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

eyuan-creare, 2021-06-17:
So this is not the correct part?<br>

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

eyuan-creare, 2021-06-17:
I'm going to leave this issue open so I can post progress of the model.

eyuan-creare, 2021-06-17:
Here is a general shape I am heading towards.  I thought it might be nice to taper on the opposite end of the SD card.  Let me know what you think.

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

I know the SD card access is still tight.  I'll work on that next.  I plan on pushing the wall in to provide a nice indentation where your fingers can grab the card.

biomurph, 2021-06-17:
Oh dang, I wanted to get the Right Angle Qwiic connector, but I got the Vertical instead!

biomurph, 2021-06-17:
I have confirmed that the distance between the Tympand E PCB and the Teensy 4.1 PCB is actually 0.165"
Also, the board edges on the USB end line up perfectly.

And yes, I did get the production Rev E delivered today!

eyuan-creare, 2021-06-17:
@biomurph Thanks for taking measurements.  What do you mean by "board edges on the USB end line up perfectly"?

- The RA Quiic would have been nice, but it's a bonus feature.  Are you saying they came with vertical connectors?

biomurph, 2021-06-17:
@eyuan-creare
When I say that the board edges line up perfectly, I mean that the edge of the Teensy board that the USB is on lines up right with the edge of the Tympan board below it. They are in alignment.

- NOTE the Qwiic connector placed is not the Qwiic connector that I requested in my BOM.

**Please proceed under the assumption that we are using the correct, RA Qwiic connector.**
I am working with Circuit Hub to address the issue.

eyuan-creare, 2021-06-17:
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
eyuan-creare, 2021-06-22:
@biomurph I could put the heat-set insert in the top case, but then I would just be screwing the PCB to the top lid.  I need a way of securing the top and bottom of the case at the end where the USB sits.

I'm finishing up the lip and should be ready soon.  If the overhang works, and the battery fits let's go that way.   If not, the hinge might work if you can print a 1/16in hole.

biomurph, 2021-06-23:
Ooooh, 1/16 hole... Not gonna happen.

Let's go with the top screw for now. Looks industrial...

eyuan-creare, 2021-06-23:
@biomurph: Just updated the repo with STEP files.

Once you print it let me know the tight spots and I can take them down.
- Battery: If it doesn't fit, try different orientations
- Lip: This helps register it but I could reduce or remove this if the 0.040 wall doesn't print.

I like the idea of translucent covers, but does that take a lot of work?  Would you rather just black out the ends of light pipes?  If so, that's a pretty easy change to the design.

I'll ship you revised hardware (the screws need to be 10mm lg)
- SCREW_PH-OVAL_M2500_045_10MM_LG_SS_MCMASTER_90258A115

Also the hole for the heat-set insert is a bit compromised by the audio jack locations.  If we need to, the hole for the insert can be opened up a bit to allow it to be epoxied in instead.

If I get time, I'll scoot over the text to make room for a Tympan logo.  I'd say we should expect one more design revision to get the fit right.

- [ ] Add an embossed area for a label.  Joel, do you have a nice label printer?
- [ ] Add icons (IN, OUT, Power I/O, Volume Triangle to show direction, Reset )

_Some Renders_

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

biomurph, 2021-06-23:
@eyuan-creare nice work!
I will get a set of these made and let you know if there is an trimming that needs done.
Thanks for ordering screws! Please let me know if they are shipped.

I will see what I can do with the logo. I have a good way to emboss the surface when it's an STL.

biomurph, 2021-06-23:
@eyuan-creare
The fit of the case lip is pretty much right on!
I'm going to apply the threaded inserts and see how it all comes together, but I think that the majority of the design is complete. The Adafruit 2000mAh battery fits nice and cozy.

It looks like the Tympan LED lights openings in the top case are the only thing out of alignment.

biomurph, 2021-06-23:
Heat press thread inserts go in great to the placements you made.
Screws that you send fit in and enclose the parts.

I think that the BOTTOM case might be a little bit too short. When I get the screws in, the opposite side on the USB end pops out a bit.
[LINK TO IMAGE](https://drive.google.com/drive/u/0/folders/1FYHjpcABMl_MS20OsRIkHAHM8Abl21QO)

Other images are located on the same [Google Drive](https://drive.google.com/drive/folders/1FYHjpcABMl_MS20OsRIkHAHM8Abl21QO?usp=sharing) folder.

I'm going to try to scale the bottom up in the vertical dimension to see if that makes a better fit. It's not really mission critical, as the parts come together in a pretty nice uint!

I will work out the Tympan Logo and light piping on my end.

Really great work @eyuan-creare !

eyuan-creare, 2021-06-23:
Looking good! Thanks for printing another iteration.  I'll check into why the bottom seems short.  Does it fit without the battery (perhaps the wires are in the way?)  Let me know if you can tell what the interference is.

For the light pipes I meant to do something like this., to bring them closer together.  I don't know if that cuts it though.  I'll think on how to get them aligned.

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

eyuan-creare, 2021-06-23:
@biomurph I'm cutting it a bit close here, where the screw boss is next to the BT module.  Can you try shaving it down?

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

eyuan-creare, 2021-06-23:
In a bit, I will upload a new model that fixes the LED alignment.<br>
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

eyuan-creare, 2021-06-23:
@biomurph Uploaded new STEP with better LED alignment.

eyuan-creare, 2021-06-23:
@biomurph Here is a section view.

biomurph, 2021-06-23:
Thanks @eyuan-creare
I don't have an issue with the BT module and the boss for the screw.
I did some mods to your models. The negative space word mark is not coming out very clearly. I'm going to try a positive.

eyuan-creare, 2021-06-23:
@biomurph Added heat set inserts for belt clip and changed lettering to allow it to print:

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

biomurph,
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

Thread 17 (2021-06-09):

Select Battery

eyuan-creare, 2021-06-09:

biomurph, 2021-06-10:
The teensy is about 60mm (2.4") long
Tympan E is 74mm (2.9") long
Tympan E is 38mm (1.5") wide
Updated Dimensions in PCB file

[Candidate 1](https://www.adafruit.com/product/258) is 1200mAh, 62mm long x 34mm x 5mm

[Candidate 2](https://www.amazon.com/Part-Number-Rechargeable-1200mAh-Connector/dp/B091FFPFB1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) is 1200mAh, 40mm long x 30mm wide x 10mm thick

[Candidate 3](https://www.amazon.com/2000mAh-Rechargable-Protection-Insulated-Development/dp/B08T6QS58J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) is 2000mAh, 50mm long x 33mm wide x 10mm thick

[Candidate 4](https://www.amazon.com/YDL-1700mAh-battery-Rechargeable-Connector/dp/B07BTRTR9R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) is 1700mAh, 52 x 28 x 10mm

@eyuan-creare I think I'm seeing a battery here that will fit to allow access to the SD card and also have enough power capacity. What do you think?

biomurph, 2021-06-10:
As per your email design idea, if you want to put a cylinder battery along side, would this work?

[Candidate 5](https://www.adafruit.com/product/1781) 2200mAh 69mm x 18mm

eyuan-creare, 2021-06-10:
Notes from @chipaudette:

The 500 mA-hr batteries really aren’t going to cut it for RevE.  They were marginal for RevD; we saw lots of brown-out behavior much earlier than I would have expected.

We’re clearly not getting as much of the battery capacity as we’d like.  I think that it’s because the regulator has more of a drop-out (at our current load) than we’d really like.  So, the battery can’t be pulled as low in voltage as its capacity rating expects.

Some current draw measurements are after my signature.  In my experience, the RevD would start to brown out (dropped BT connections is the first symptom) as we started to get towards two hours…shorter if writing to the SD card.  The RevE will be worse.

In my opinion, 500 mA-hr is too small for RevE.

Data, January 2021

Tympan RevD: Power draw seems to be 160 mA
•	2-channel, 96 kHz sample rate
•	BT is on but not connected to anything
•	SD card inserted but not being used
•	Frequency-domain audio processing load of 78% of CPU

Tympan RevE: Power draw seems to be 178 mA
•	2-channel, 96 kHz sample rate
•	BT is on but not connected to anything
•	SD card inserted but not being used
•	Same Freq-domain audio processing, but the faster CPU results in only 11% usage

eyuan-creare, 2021-06-10:
@biomurph To ship lithium batteries, they need to be tested to UN38.3.  Otherwise they must be shipped hazardous material (class-9) which has a hefty fee.

There are a few battery places overseas that can perform this test cheaply such as sz-battery.
- 20 business days for attaching leads then testing.
- $500 testing + 10cells + 10 batteries to be destroyed

For cost, 2-3AHr Li-poly batteries were around $5/ea in quantities of 10 to 25 pcs.'

Lead time is long, and we would need to verify the testing is legit.'

biomurph, 2021-06-10:
@eyuan-creare that may be more than we can realistically pull off in the near term. I would like to use one of the batteries listed. I don't have a problem with shipping via UPS or other. When I do, it does not go on a plane or it goes on a special plane.

I think the testing is overkill. Is this something that Create has specified?

biomurph, 2021-06-10:
I'm asking if candidate 4 is tested to the spec.
I always just assumed that if they were shipped to me, they are OK. Also, they do have overcurrent protection on them.

I do follow the guide when I do shipping with UPS, for example, There is a way to check a box and tell them there is lithium battery enclosed inside product. I never have a problem at all.

eyuan-creare, 2021-06-10:
Perhaps there are more stringent rules depending on the definition of a distributor, rather than a private individual.

biomurph, 2021-06-10:
could be. I am very comfortable shipping under my account any of the batteries that are listed.

In looking for the spec test, I realize that Candidate 3 is not an option because it uses a smaller JST (1.25mm, not 2mm pitch).

eyuan-creare, 2021-06-16:
Sweet! I tracked down the UN38.3 test report for Adafruit's 2000mAh battery:
[LP803860_UN38-3.pdf](https://github.com/Tympan/Tympan_Rev_E_Hardware/files/6665854/LP803860_UN38-3.pdf)

If we wanted to order in bulk (and didn't mind long lead times) we could order straight from [PKCell](http://www.batterypkcell.com/un38-3-certificate/):

biomurph, 2021-06-16:
Ok! We will use that size for this build.
I'll look at the lead times. Might be OK to get a small amount right away and wait for the rest

eyuan-creare, 2021-06-17:
I'm open to what battery we use, but that 2000mAh fits so nicely.  If we want to leave extra room let me know by Thurs morning as I am beginning to shape the case.

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

biomurph, 2021-06-17:
Let's stick with the Adafruit 2000mAh battery.
Also, please check the lead length of the battery connector. You might need to flip the battery around so the cable is at the USB end?

eyuan-creare, 2021-06-17:
Sounds good.  The battery lead is 4.25in so it should work either direction.

eyuan-creare, 2021-06-17:
Closing this out.  I'll design around the Adafruit 2000mAh li-poly, unless it can't fit.

Closed 2021-06-17.

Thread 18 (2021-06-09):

Expose SD Card

eyuan-creare, 2021-06-09:
### Options
1. Bump in the case and move the battery back

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

2. Place a 18650 to the side

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

chipaudette, 2021-06-09:
Are there easily-obtained cylindrical cells that are narrower than the 18650?  Like, are 14500 readily available?  https://en.wikipedia.org/wiki/List_of_battery_sizes#Cylindrical_lithium-ion_rechargeable_battery

eyuan-creare, 2021-06-09:
Fenix is a popular brand among flashlight enthusiasts, so I believe it's 1600mAh rating .  However it is unlikely we will find an off the shelf battery with **leads**.  I just don't like widening the case, even if it is less overall volume.

https://www.batteryjunction.com/fenix-arb-l14-1600u.html

biomurph, 2021-06-10:
We have two issue threads covering this problem.
@eyuan-creare @chipaudette
I have put candidates on the other thread for flat pack and cylinder battery options to review.

eyuan-creare, 2021-06-10:
@chipaudette, @biomurph I'd like to rule out a battery on the side.  I think it makes the case too awkward to put in your pocket and prefer making the case jog in to expose the SD card.  Do you agree?  Should we move forward with option 1?

biomurph, 2021-06-10:
I would also prefer not to have the battery on the side.
If one of the candidates from the other thread will work, and fit to allow access to the SD card, then awesome!

chipaudette, 2021-06-10:
The jog in the case is not my favorite (it makes my mind think about our not-so-attractive RevC case) but if everyone else has reservations with the side battery, I'm not opposed to the job in the case.

I support the job in the case enough to take the next few steps in the design process: (1) pick a candidate battery, (2) insert the battery in the model, (3) conceptually decide where our fasteners will go, (4) illustrate the new SD slot and so that we see how easy/hard it might be to access the card.

chipaudette, 2021-06-10:
I do have concerns over the difficulty of getting the card in and out (hency my request for bullet #3 above).  As currently drawn, the jogged wall really blocks your fingers from holding the SD card as you try to slide it in/out.

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

That's the kind of access issue, though, that I'm looking for ideas on.

eyuan-creare, 2021-06-10:
Also, it can be difficult to guide the card into the slot without some support.  And adding support to the case can be difficult depending on whether PCBs need to slip past the support to be installed.

Here are some options for exposing the card:

1. We let the SD card stick out a bit and create an indentation for your fingernails or tweezers to get in there

2. We make a false cover that clips in. If we are feeling adventurous, we could make it flip out on a living hinge.  That would retain the original look somewhat but is a bit of a design effort and limits material choices.

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

PDF to scale:
[case_ideas.pdf](https://github.com/Tympan/Tympan_Rev_E_Hardware/files/6632964/case_ideas.pdf)

@biomurph What kind of materials can you print, and what colors can you do?

chipaudette, 2021-06-10:
If you're proposing the 2000 mA-hr, where do the fasteners down there fit?  Or are you saying we don't need fasteners down there?

eyuan-creare, 2021-06-10:
@chipaudette: Both the Adafruit 2000mAh and 1200mAh are 2.4" in length.

For option 1, If we need to we can lengthen the case to clear the battery wires and make a large indention for the USB plug.  It will take some effort to mock up so we should choose which design you like best (given the risk of more complex designs) and run with it till it breaks.

biomurph, 2021-06-10:
I want to make this happen with as little adventure as possible. The case print files should be easy for anyone to print on their own.

I have a Tax mini 2, and it rocks PLA all day! Any color

biomurph, 2021-06-10:
Also, @eyuan-creare you're only showing the side view. We may get a better sense of access with a view from the short end?

I don't mind a cut away that is kind of like the Rev C, personally. But again, if it can be easy (in quotes).

The lipos that I have listed in the other thread are preferred because they are accessible and affordable.please use dima from those only

eyuan-creare, 2021-06-10:
Here is another option, though I am doubtful that we can source a battery narrow enough to fit between the headers.  We would likely drop in capacity quite a bit to make this happen.

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

eyuan-creare, 2021-06-10:
Here's a view of the existing case looking into the audio jacks.  Pink is the SD card.  I also updated the scale drawing.
[2021-0610-01_case_ideas.pdf](https://github.com/Tympan/Tympan_Rev_E_Hardware/files/6633821/2021-0610-01_case_ideas.pdf)

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

eyuan-creare, 2021-06-11:
@chipaudette You asked about locating screws.  I had to do a workaround for the last revision too, where the heat set inserts are above the battery.

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

For the single screw near the USB connector, we would need to do something similar.

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

Since Joel will be printing them, it gives us a chance to do more iterations.  We could consider a snap fit case, depending on how elastic the PLA material is.

biomurph, 2021-06-11:
I have found that I get a nice tight for with the forms from RevD. If you can look at those models in the Rev D repo, the way the cases fit comes out good on my machine.

I would avoid a fit that relies on the plastic unless it is robust clip on one end and screw on the other? Snap fit becomes break fit after a while.

I do want to use the threaded inserts on this build. They are nice

biomurph, 2021-06-11:
I've just looked around and it seems that PET or PETG would be a good material instead of the PLA.
I think that for the near term, I will use PLA because I have yield from my printer, and then transition to the PETG when there's time to tweak and twiddle the print settings. I have read that it will print as easily as PLA, but getting there can be a bit of a climb. Also, there may be issues with support removal and 'stringing', that is, stringy strings around the part left during print head moves. All of this sounds like it can be overcome and prints will come out good, but for our close deadlines I want to use what I know works.

When I get a more UV resistant material, I will can send out replacement cases

eyuan-creare, 2021-06-11:
Perhaps this is a combination of practical and shapely.  There would only be two screws to access the SD card.  It's possible we could make the bottom half snap fit onto the top, with screw holes in case you wanted it to be more secure.

@chipaudette, @biomurph  if you have time today, perhaps we should all chat.  My schedule is pretty free.

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

biomurph, 2021-06-11:
I will be able to be on the phone later today.

I think that the idea of a 'hook' or 'tab-slot' type capture on the USB end, while having a screw on the jack end could be nice.

Are you now thinking that we *won't* be putting a slot for the SD and that it will be accessed via case removal?
This would be good *if* we can get the SD card playback working, is that correct?

eyuan-creare, 2021-06-11:
The idea behind (7) is that the bottom would be easily removeable, by snap fit to the top or perhaps sliding in, or screws.  That way a user could easily access the SD card or swap a battery. It will take some geometry acrobatics to make it happen.  If I have trouble, then I could revert to a snap in cap (3) which would be a 3pc design.

If we wanted the SD card more accessible, then I think a bump out like (1) or (4) would work.

biomurph, 2021-06-11:
OK!

I am all for whatever is going to be the most easiest to model, print, assemble, etc.
If it's a removable bottom to get the SD card out and option to swap battery, that's kinda cool!

I have had some luck myslef with a 'one end latch, the other end screw' design. That might be the easiest.

chipaudette, 2021-06-11:
SD Playback (if you're referring to the bug identified by our friends in Montreal) is unrelated to the need to physically access the SD card.  They are separate issues.

What would relieve our need for physical access is if the MTP functionality were to suddenly be much more mature and if it were part of the Teensyduino install.  MTP lets you electronically access the SD card through the Tympan from your PC.  It basically turns your Tympan into an SD reader such that you never need to physically remove the SD.

Unfortunately, MTP is neither mature enough nor part of the Teensyduino installation, so having physical access to the SD still seems important.

chipaudette, 2021-06-11:
@eyuan-creare , I am open to using screws (concept 7).  Looking back at Concept 1, I see that your rendering of Concept 4 actually addresses most of my concerns about getting your fingers / tweezers onto the SD card.

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

The part of Concept 4 that is the crucial difference from Concept 1 is that you have raised that upper wall to get it a bit more out of the way of the SD slot.  To me, that seems like enough of a shift to make it workable, even without the SD holder.

What do y'all think of modifying Concept 1 to have the higher wall of Concept 4 (but otherwise staying as Concept 1)??

If it were to work for you, then we'd "just" have to figure out how to do the fasteners (and/or hook) and how to make room for the lead wires to come off the battery.

eyuan-creare, 2021-06-11:
Yes, there shouldn't be a problem raising that wall.  That 3-pin header between the audio jacks shouldn't be there in a production unit.  Though we may want to leave a wall so that the SD card slides against something.  The tip of the SD card has an edge to it that could allow a screwdriver or pick to flick it out.

eyuan-creare, 2021-06-17:
Closing this, as we decided on an approach.  I'll follow up with updates on #15

Closed 2021-06-17.

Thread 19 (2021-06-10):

Preinstall an SD card?

chipaudette, 2021-06-10:
Depending on what we decide for the enclosure, do we preinstall an SD card in the ASA units?

biomurph, 2021-06-10:
Yes, depending.
I would prefer not to have to add an SD card to the BOM, but it would ensure that they get a good, fast card.

Would [these](https://www.amazon.com/JUANWE-High-Speed-Smartphone-Bluetooth-Speaker/dp/B086DKQQ6F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) cards be a good candidate? They don't seem to have any speed certification, but they are cheap... you do get what you pay for...

chipaudette, 2021-06-10:
For recording audio, the Tympan RevD has been *extremely* sensitive to the card that one uses.  I can't speak to SD on the RevE.

For the RevD, we've used [SanDisk Ultra 32GB](https://www.amazon.com/SanDisk-Ultra-microSDXC-Memory-Adapter/dp/B073JWXGNT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).  Chris found these.  None of the other SD cards gave nearly as good performance.

Recently, we had a hard time getting the Ultra, so we bought some [SanDisk Extreme 32GB](https://www.amazon.com/SanDisk-Extreme-Memory-Adapte-SDSDQXN-032G-G46A-Version/dp/B00M55BS8G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).  We don't know if they perform as well as the Ultra.  Anecdotally, Chris has not had quite as good an experience, but the underlying SD library has been changing, too.  So it's hard to know.

We should not use the cheapest cards as everyone will just be disappointed with the inability to write audio without hiccups showing up every few seconds.

I'm not proposing that we pre-install SD cards long-term.  I'm only proposing that we do it for the ASA units.  I vote that we use the best cards that we know about.

biomurph, 2021-06-10:
@chipaudette I agree that we should use the best, and that the low cost ones can be glitchy.
In my experience, I use lower level mcu that do not run native SD (they use and SPI hack). Those systems definitely need high quality SD cards. Now I know that the Teensy (and Tympan) do as well.

It would be a nice perk to add the SD card to the ASA kit. I will look for the ScanDisk Ultra.

biomurph, 2021-06-10:
I've sourced the ScanDisk Ultra 32GB

chipaudette, 2021-06-10:
Thanks Joel.  When I said  "We can buy them", I meant "Creare can buy them".  Upon re-reading, that wasn't clear.  Sorry.  If you would prefer that Creare buy them, let me know.

biomurph, 2021-06-10:
I'll email you a link to the cards.

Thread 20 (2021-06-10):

Adding Flash and RAM

biomurph, 2021-06-10:
Teensy 4.1 had two SMT pad locations for a Flash chip and a RAM chip.
I'm planning to install both on the ASA challenge boards.

@chipaudette were you able to make use of them on the prototype boards?

chipaudette, 2021-06-10:
Sorry, no.  I have not tried them.

There's some learning to be done for me to figure out how to use them.  That's part of what's held me back.  Do you know the forum threads where they talk about using them?

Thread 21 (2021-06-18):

June 2021 Production BC127 Melody Version

biomurph, 2021-06-18:
Been poking at the new hardware and testing the BC127.
I programmed the example sketch  `RenameTympanBT` from the `feature_Teens4_SD_ble` branch of the Library
I changed line 36 to `TympanRev::E` instead of `TympanRev::D`

I'm using the Beta 9 version of Teensduino in Arduino 1.8.15
Running on MacOS Big Sur 11.4

Side note: I had to disable my virus software to run Teensyduino. It was crashing on some library example...

This is the serial port out put from the RenameTympanBT sketch.
This module is running on Melody 6. It's likely that all 40 of this production run are Melody 6.
There definitely seem to be some basic coms differences between 6 and 7. The uniqui ID is there, but the current firmware doesn't parse it well.

From past history, I think the plan is to roll back the Melody version, since we are dependent upon the Bluetooth and all of our phone apps know is Melody 5.

One feature that we will lose is the low-latency that the versions 6 and 7 offer.
I think it's a long-term feature add to upgrade our firmware and apps to interface with Melody 7.

Tympan: forceBTtoDataMode: Setting PIO5 to HIGH
*** RenameTypmanBT.  Starting...
*** Switching Tympan RevD BT module into command mode...
Tympan: forceBTtoDataMode: Setting PIO5 to LOW
*** Should be in command mode.
*** Clearing buffers.  Sending carraige return.
ERROR 0x0012*** Should have gotten 'ERROR', which is fine here.
*** Restoring factory defaults...
BlueCreation Copyright 2017Melody Audio V6.1.5 HDBuild: 14969OKBlueCreation Copyright 2017Melody Audio V6.1.5 HDBuild: 14969*** Reset should be complete.  Did it give two 'OK's, an ID blurb, and then 'READY'?
*** Begin renaming process.  Getting BT name...*** Response = NAME=BC-1C1427OK
*** Processing name info...
*** Desired New BT Name = TympanE-
*** Setting New BT Name...TympanE-
OKOKNAME=TympanE-OK*** Name setting complete.  Did it return the desired name?
*** Setting GPIOCONTROL mode to OFF, which is what we need...
ERROR 0x001AOK*** Changing into transparanet data mode...
ERROR 0x0012Tympan: forceBTtoDataMode: Setting PIO5 to HIGH
*** BT Setup complete.
*** Now entering BT <-> USB Echo mode...feel free to send messages back and forth.

chipaudette, 2021-06-18:
Yes, the short / medium plan is to ensure consistency across the fleet...by rolling back to V5.5.  This is what the App has been tested with.

Chip

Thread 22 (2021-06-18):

June 2021 Production AIC Shield Quad Pass Thru

biomurph, 2021-06-18:
The Quad Pass Through sketch from the examples is not working.
I'm getting a pile of I2C errors. I believe that this is not functional yet?

Library branch: feature_Tympan4_SD_ble
Teensyduino beta9, Arduino 1.8.15

chipaudette, 2021-06-18:
Did you change **both** lines to enable RevE?

```
Tympan                        myTympan(TypmanRev::E);    //note: Rev C is not compatible with the AIC shield
AICShield                     aicShield(TympanRev::E, AICShieldRev::A);   //note: Rev C is not compatible with the AIC shield
```

biomurph, 2021-06-18:
That fixed it!
AudioPassThruQuad Test Passed!

Closed 2021-06-18.

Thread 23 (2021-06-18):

BC127-HD Firmware Issue

biomurph, 2021-06-18:
@chipaudette
We have an issue with the BC127.
The module that we got in our build is the BC127-HD variant.
It came shipped with the Melody v6.1.5 HD firmware.

I followed the instructions on our BC127 firmware up/down grade repo, and went through the process as far as downloading existing firmware from the target (it was not an option to just upload). I got the following error from the DFU Wizard

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

Then
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

I tried to upload every version of Melody that we are hosting in the repo, and got the same error. Then, I went to the [Melody firmware page at Sierra](https://source.sierrawireless.com/resources/airprime/software/bc127-firmware/#sthash.6BZB9aeb.dpbs) and it looks like there are releases that are only for the HD variant. The earliest version that they offer is the version 6.1.1 HD. For more about what that means, I looked into the [Melody v6 User Guide](file:///Users/biomurph/Downloads/41110747%20MelodyAudio6%20User%20Guide_r3.pdf) at the bottom (page 88 on) is a list of the change logs. At least that's something! It says that the HD variant is only starting to be available in Melody 6.1.1.

FYI the `HD` is referring to aptx HD, which is some Qualcomm trademarked nonsense that means the audio is *high definition*. [HERE](https://www.soundguys.com/the-ultimate-guide-to-bluetooth-aptx-and-aptx-hd-19914/) is a link that talks about the difference it makes.

I did try to run the Melody DFU Uploader.exe program but it is not connecting. Likely this is because it tries to tell the BC127 to go into DFU mode, but that is what our arduino dfu firmware is already doing... (?)

In the end, I was able to use the DFU Wizard to upload a clean copy of the Melody 6.1.5 HD firmware to the module.

I'm going to downgrade to the Melody v6.1.1 to see if that makes any difference in our ability to control the module and then report back on this issue thread.

biomurph, 2021-06-18:
Just successfully uploaded the Melody v6.1.1 to Tympan E BC127 radio module.
Then I programmed the Teensy 4.1 with the RenameBT.ino code.
This is the serial output from that sketch

*** RenameTypmanBT.  Starting...
*** Switching Tympan RevD BT module into command mode...
*** Should be in command mode.
*** Clearing buffers.  Sending carraige return.
ERROR 0x0012*** Should have gotten 'ERROR', which is fine here.
*** Restoring factory defaults...
BlueCreation Copyright 2016Melody Audio V6.1.1 HDBuild: 14861OKBlueCreation Copyright 2016Melody Audio V6.1.1 HDBuild: 14861*** Reset should be complete.  Did it give two 'OK's, an ID blurb, and then 'READY'?
*** Begin renaming process.  Getting BT name...*** Response = NAME=BC-1C1427OK
*** Processing name info...
*** Desired New BT Name = TympanE-
*** Setting New BT Name...TympanE-
OKOKNAME=TympanD-OK*** Name setting complete.  Did it return the desired name?
*** Setting GPIOCONTROL mode to OFF, which is what we need...
ERROR 0x001AOK*** Changing into transparanet data mode...
ERROR 0x0012*** BT Setup complete.
*** Now entering BT <-> USB Echo mode...feel free to send messages back and forth.

chipaudette, 2021-06-18:
V5.5 is our baseline, not V6.

biomurph, 2021-06-18:
I have been digging around and I can't find an easy fix for this.
I put up a post on the Sierra forum
https://forum.sierrawireless.com/t/change-melody-firmware-v6-1-5-hd-to-v5-5rc11/24042

I think that the Melody DFU Tool might be an option, but will have to create a Teensy code that will interface with it. I think that the Melody DFU wants to send the initial signal that will put the module into DFU, and there is some kind of back-and-forth necessary for it to operate. This is all doable, but it would be good to know if it is a possibility and hopefully the forum will respond positively.

It does look like any update on our end to interface with the newer firmware is not trivial, but it is doable.

It's a problem working on from a firmware base that is 4 years old and made by a company that doesn't exist any more (Blue Creation, that is).

I'm watching the forum. I'll start work on getting the Teensy side of the module communication working clearer in the RenameBT sketch.

chipaudette, 2021-06-18:
Sorry that I missed your earlier posts about V5.5 not being feasible due to the HD variant.  I was trying to do too many things at once.  My bad.

I've found little help from Sierra themselves on these products, so I'm not hopeful for your request.  My fingers are crossed.

If it turns out that the new module is not the same hardware as the old one, and that it simply can't host the V5 firmware, that's an unfortunate problem.  Suddenly, we'll have an unplanned hard break in our bluetooth compatibility between RevD and RevE that we'll have to deal with.  Ugh.

You should probably send us a unit so that we can get a feel for the magnitude of the problem.  We could put V6 on one of our units, but I fear that we wouldn't capture all of the nuance of what might be different with the hardware.  If we're going to do some quick testing to see the problem, we should be working with the actual production hardware.

Can you send us a unit?

biomurph, 2021-06-18:
Yes! It will go out in tomorrow's delivery complete with teensy, etc

chipaudette, 2021-06-24:
For RevE, I got the new BC127 module to work.

I had to upgrade:
•	Upgrade the firmware on the BC127 to the V7.3 HD version.
•	Alter the BLE classes in the Tympan_Library

Unfortunately, the BLE message format is a little different between V5.5 and V7.3HD, so one has to tell the BLE class which version of the firmware you’re using.  That’s crappy.  Maybe we can be smarter later.  Right now it defaults to V7, assuming that you will upgrade all the new RevE to V7.

Note that I did start with trying to be compatible with the V6 firmware that came on the hardware.  It seemed to have some message formatting issues that made our end much harder.  The V7 firmware went back to some of the message formatting qualities from the V5 firmware, so it was much easier for me.

The new Tympan_Library has only been tested on the single RevE that you sent me and only with the V7.3HD firmware.  Also, there is still some stuff in the class that doesn’t quite work (like, most importantly, the method “setupBLE()”).  As a result, it is only held in a branch in the repo and not yet merged into either develop or master.  For your own trials, you can try out the branch here (after upgrading your firmware to V7.3HD, of course):

https://github.com/Tympan/Tympan_Library/tree/feature_BC127_V7

For my trials, I’ve been using the sketch in the Tympan_Library: “01-BasicGain_wApp”.  The only change that you need to do is to bypass the afore-mentioned failure of “setupBLE”.  Comment it out and replace it with this:

//ble.setupBLE(myTympan);  //original
ble.advertise(true);  // new

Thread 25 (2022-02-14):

BC127 Module Variant Availabiltiy

biomurph, 2022-02-14:
@chipaudette @eyuan-creare

I have Tympan Rev E boards prototyped to test the only available BC127 modules.
The two modules that are available are:

- [BC127-EXT-HD](https://www.digikey.com/en/products/detail/sierra-wireless/BC127-EXT-HD-1104314/11657575)
- [BC127-EXT-APTX](https://www.digikey.com/en/products/detail/sierra-wireless/BC127-EXT-APTX-1103783/7801750)

The current Melody Firmware that we are using is the `Melody 7.3-HD`.
I have uploaded the latest Melody Firmware v7.3 to the modules under test, but neither of them would take the `Melody 7.3-HD` which we are currently using. They only take the `Melody 7.3-STANDARD` firmware.

I don't know what the difference is between these firmware variants, but I am hoping that it is negligible or not applicable to our application.

I need to solder in the through-hole components to these boards and then run tests with the Tympan Remote app.

Do you have any suggestions for the best app example for testing? I am hoping that there is a GO / NO GO test that can be run to verify these modules with the STANDARD firmware. If I get the basic gain app running and connected to the Tympan under test and the behavior is as expected, is that enough to call it good?

I will ship one of these to you so that you have one in house that you can test with if we run into a jam.

eyuan-creare, 2022-02-14:
Thanks for your due diligence on this.  In case it helps, I just received an order from Digikey for standard BC127 modules, however, the order was placed 5months ago.

biomurph, 2022-02-15:
How many did you order?

chipaudette, 2022-02-15:
@biomurph, the `Melody 7.3-HD` firmware ought to work, but only with the BC127-EXT-HD version of the module.  For the BC127-EXT-APTX module, I'm guessing that only the `Melody 7.3-STANDARD` would work (unless there were to be some sort of `Melody 7.3-APTX` version available from Sierra).

chipaudette, 2022-02-15:
As for testing / debugging, I don't think that I have anything as simple as go/no-go...but if you (1)  get the Basic Gain sketch running on the tympan, (2) you can connect from the phone App, and (3) you can make changes from the phone and have the Tympan sound different (ie, get louder), you win!

Another test would be to run this example sketch: https://github.com/Tympan/Tympan_Library/blob/main/examples/07-Bluetooth/BasicGain_wApp_BLEdebug/BasicGain_wApp_BLEdebug.ino

In that sketch, open the Serial monitor and restart the Tympan.  Watch all the debugging messages as it tries to talk to the Bluetooth module.  If you get sensible replies (as opposed to ERRORS, or as opposed to no replies at all), you're probably good.  Also, you can try connecting from your phone and this sketch will spew more debugging info to the Serial Monitor during that connection process.

biomurph, 2022-02-15:
@eyuan-creare
I plan to have on the order of 50+ units made, so the 10 you have are not useful.
If you have a contact info for sales rep, please pass it on. I have had horrible experience in communicating with them.

@chipaudette
Both of the units, the `BC127-EXT-APTX` and the `BC127-EXT-HD` would only take the `Melody 7.3-STANDARD` firmware. I tried to put the `Melody 7.3-HD` firmware on them and the firmware updater failed to load with an error saying that the hardware is incompatible. So we're running with the `STANDARD` version.

I was able to get the BasicGain_wApp running connected to the Tympan Remote App (Android), and saw no errors in the serial port. All behavior seems normal there.
I will re-test with the BLEdebug code you point to to make sure there are no errors.
If (when!) there are no errors, I will pack one of the `APTX` Tympan up and ship it to you so that you can have one. I have the case printed in a different color to differentiate it from any other Tympan you might have laying about. Pics coming on this thread.

For clarity and to avoid confusion:

- `EXT` means that the antenna is external, and I need to design antenna circuitry for it
- `HD` means high definition audio. Not sure why they do that...
- `APTX` means you get access to the aptX features. Which ones are included? I don't know, but I'm hoping the [low latency](https://www.aptx.com/aptx-low-latency) is available for us to play with.

chipaudette, 2022-02-15:
The units that you built for ASA used the BC127-HD (not "ext"), right?  Those modules required the HD version of the firmware.  If the new units truly are BC127-EXT-HD, I'm shocked that they do not use the HD firmware.

In the end, I don't really care either way.  We don't use the HD mode, so it's irrelevant to us.  If the system runs, that's good enough for me.

biomurph, 2022-02-15:
@chipaudette
I'm not too surprised about the HD weirdness. Par for the course with Sierra Wireless.
They 'work' with the debug code. No errors!

I'm shipping one to Creare. Who's attention should it go to?

I printed a green cover so we can tell them apart as prototypes ;)

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

biomurph, 2022-02-15:
@eyuan-creare
I saw your email from the Sierra folks.
Let me know if I can help out with your application.
I have a branch of this repo called [bc127-EXT](https://github.com/Tympan/Tympan_Rev_E_Hardware/tree/bc127-ext) which has the chip antenna circuit and layout on it, which you may be able to use?

chipaudette, 2022-02-15:
@biomurph , Cool.  You can send it to my attention.

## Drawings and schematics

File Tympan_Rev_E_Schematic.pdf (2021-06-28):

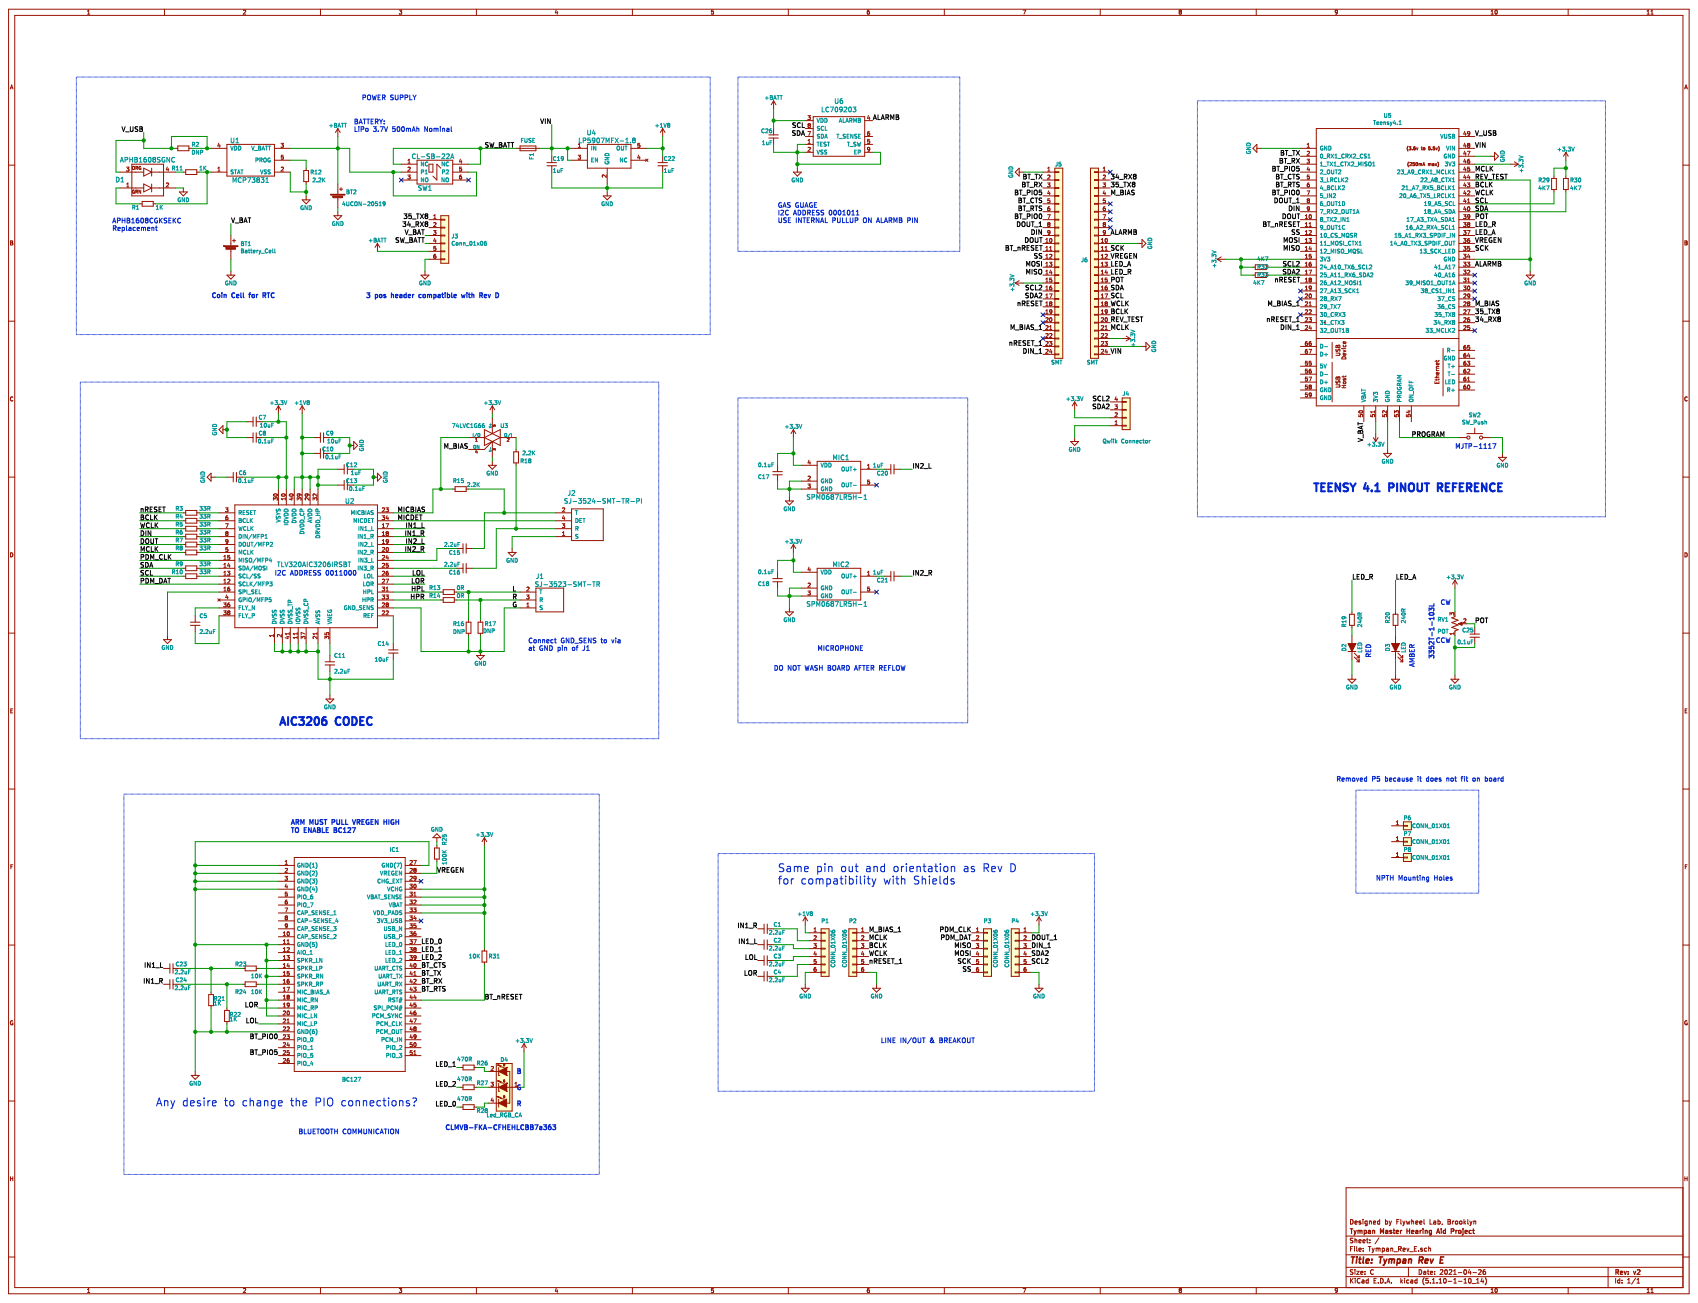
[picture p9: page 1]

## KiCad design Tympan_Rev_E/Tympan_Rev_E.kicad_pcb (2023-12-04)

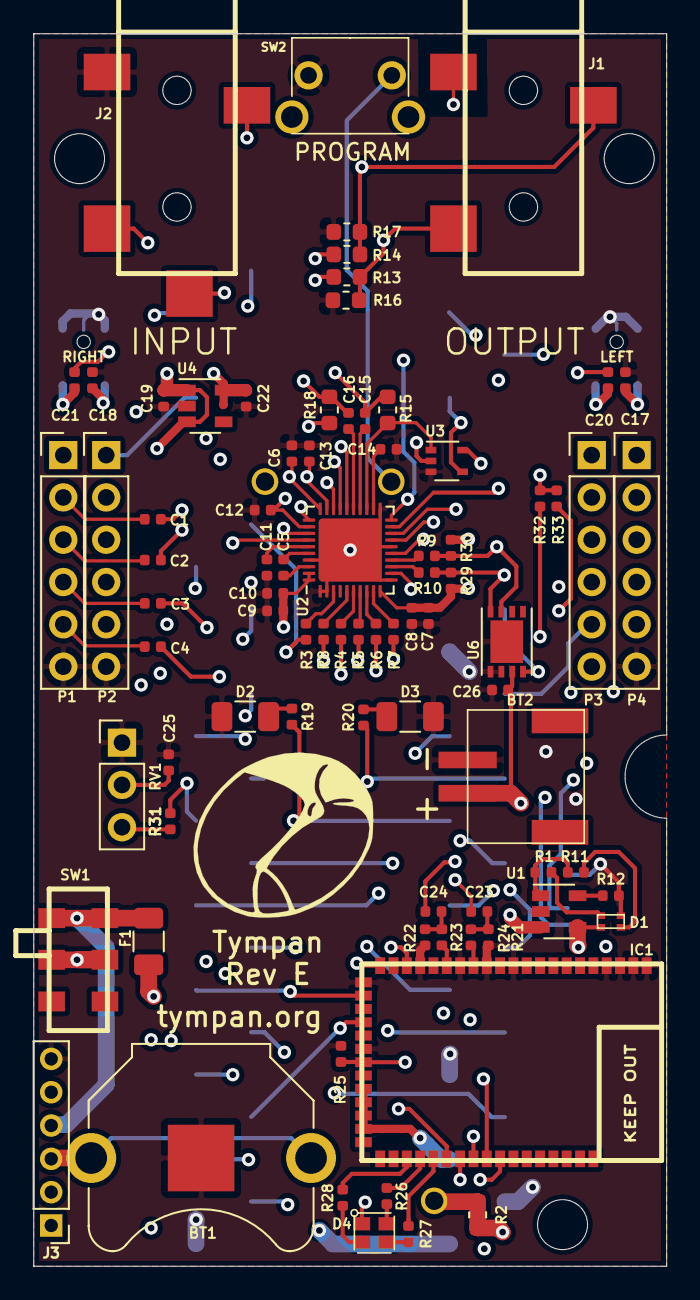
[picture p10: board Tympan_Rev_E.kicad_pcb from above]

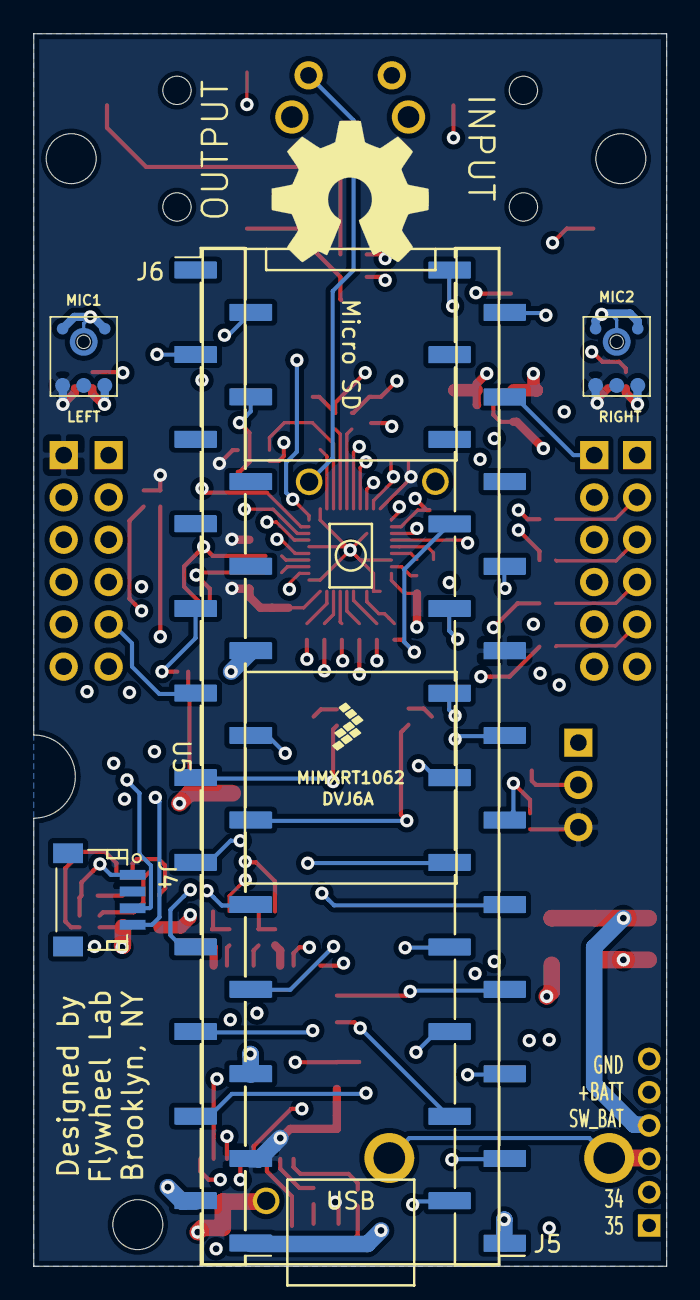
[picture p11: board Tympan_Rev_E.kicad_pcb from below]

Board: 4 copper layers, 38.0 x 74.0 mm, 91 parts (6 on the bottom side), 95 nets.

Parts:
BT1: Battery_Cell; BatteryHolder_Keystone_3001_1x12mm
BT2: 4UCON-20519; 4UCON-0217-20519
C1, C2, C3, C4, C5, C11, C15, C16, C23, C24: 2.2uF; C_0402_1005Metric
C6, C8, C10, C13, C17, C18, C25: 0.1uF; C_0402_1005Metric
C7, C9, C14: 10uF; C_0402_1005Metric
C12, C19, C20, C21, C22, C26: 1uF; C_0402_1005Metric
D1: APHB1608SGNC; ABHB1608S
D2, D3: LED; C_1206_3216Metric
D4: Led_RGB_CA; CLMVB-FKA-CFHEHLCBB7a363
F1: FUSE; C_1206_3216Metric
IC1: BC127
J1: SJ-3523-SMT-TR
J2: SJ-3524-SMT-TR-PI; SJ-3524-SMT-TR
J3: Conn_01x06; Pin_Header_Straight_1x06_Pitch2.00mm
J4: Qwiik Connector; JST_SH_SM04B-SRSS-TB_04x1.00mm_Angled
J5, J6: Conn_01x24; Pin_Header_Straight_1x24_Pitch2.54mm_SMD_Pin1Left
MIC1, MIC2: SPM0687LR5H-1
P1, P2, P3, P4: CONN_01X06; PinHeader_1x06_P2.54mm_Vertical
P6, P7, P8: CONN_01X01; MountingHole_3mm
R1, R11, R21, R22: 1K; R_0402_1005Metric
R2, R16, R17: DNP; R_0603_1608Metric
R3, R4, R5, R6, R7, R8, R9, R10: 33R; R_0402_1005Metric
R12: 2.2K; R_0402_1005Metric
R13, R14: 0R; R_0603_1608Metric
R15, R18: 2.2K; R_0603_1608Metric
R19, R20: 240R; R_0402_1005Metric
R23, R24, R31: 10K; R_0402_1005Metric
R25: 100K; R_0402_1005Metric
R26, R27, R28: 470R; R_0402_1005Metric
R29, R30, R32, R33: 4K7; R_0402_1005Metric
RV1: POT; PinHeader_1x03_P2.54mm_Vertical
SW1: CL-SB-22A
SW2: SW_Push; MJTP1117
U1: MCP73831; SOT-23-5
U2: TLV320AIC3206IRSBT; UQFN-40-1EP_5x5mm_P0.4mm_EP3.8x3.8mm
U3: 74LVC1G66; SOT-353_SC-70-5
U4: LP5907MFX-1.8; SOT-23-5
U5: Teensy4.1; Teensy41_SMT
U6: LC709203; WDFN8_3X4mm_0.65P

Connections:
+1V8: C9.1, C10.1, C12.1, C13.1, C22.1, P1.1, U2.29, U2.32, U2.39, U2.40, U4.5
+3V3: C6.2, C7.2, C8.2, C17.2, C18.2, D4.1, IC1.30, IC1.31, IC1.32, IC1.33, J4.2, J5.15, J6.22, MIC1.4, MIC2.4, P4.1, R29.1, R30.1, R31.2, R32.2, R33.2, RV1.3, U2.10, U2.30, U3.5, U5.15, U5.46
+BATT: BT2.1, C26.1, J3.5, SW1.2, SW1.5, U1.3, U6.3
/34_RX8: J3.2, U5.26
/35_TX8: J3.1, U5.27
/ALARMB: U5.33, U6.4
/BCLK: P2.3, R4.1, U5.43
/BT_CTS: IC1.40, U5.5
/BT_PIO0: IC1.23, U5.7
/BT_PIO5: IC1.25, U5.4
/BT_RTS: IC1.43, U5.6
/BT_RX: IC1.42, U5.3
/BT_TX: IC1.41, U5.2
/BT_nRESET: IC1.44, R31.1, U5.11
/DIN: R6.1, U5.9
/DIN_1: P4.3, U5.24
/DOUT: R7.1, U5.10
/DOUT_1: P4.2, U5.8
/HPL: R13.1, U2.31
/HPR: R14.1, U2.33
/IN1_L: C2.1, C23.1, U2.17
/IN1_R: C1.1, C24.1, U2.18
/IN2_L: C20.1, U2.19
/IN2_R: C21.1, U2.20
/L: J1.2, R13.2, R16.1
/LED_0: IC1.37, R28.1
/LED_1: IC1.38, R26.1
/LED_2: IC1.39, R27.1
/LED_A: R20.1, U5.37
/LED_R: R19.1, U5.38
/LOL: C3.1, IC1.21, U2.26
/LOR: C4.1, IC1.19, U2.27
/MCLK: P2.2, R8.1, U5.45
/MICBIAS: R15.1, U2.23, U3.1
/MICDET: J2.4, U2.34
/MISO: P3.3, U5.14
/MOSI: P3.4, U5.13
/M_BIAS: U3.4, U5.28
/M_BIAS_1: P2.1, U5.21
/PDM_CLK: P3.1, U2.15
/PDM_DAT: P3.2, U2.12
/POT: C25.1, RV1.2, U5.39
/PROGRAM: SW2.1, U5.53
/R: J1.3, R14.2, R17.1
/SCK: P3.5, U5.35
/SCL: R10.1, R29.2, U5.41, U6.8
/SCL2: J4.4, P4.5, R32.1, U5.16
/SDA: R9.1, R30.2, U5.40, U6.7
/SDA2: J4.3, P4.4, R33.1, U5.17
/SS: P3.6, U5.12
/SW_BATT: F1.2, J3.4, SW1.1, SW1.4
/VIN: C19.1, F1.1, U4.1, U4.3, U5.48
/VREGEN: IC1.28, R25.1, U5.36
/V_BAT: BT1.1, J3.3, U5.50
/V_USB: D1.3, R2.1, R2.2, U1.4, U5.49
/WCLK: P2.4, R5.1, U5.42
/nRESET: R3.1, U5.18
/nRESET_1: P2.5, U5.23
GND: BT1.2, BT2.2, C6.1, C7.1, C8.1, C9.2, C10.2, C11.2, C12.2, C13.2, C14.2, C17.1, C18.1, C19.2, C22.2, C25.2, C26.2, D1.2, D2.1, D3.1, IC1.1, IC1.2, IC1.3, IC1.4, IC1.11, IC1.13, IC1.15, IC1.18, IC1.20, IC1.22, IC1.27, J1.1, J2.1, J3.6, J4.1, MIC1.2, MIC1.3, MIC2.2, MIC2.3, P1.6, P2.6, P4.6, R12.2, R16.2, R17.2, R21.2, R22.2, R25.2, RV1.1, SW2.2, U1.2, U2.1, U2.2, U2.11, U2.16, U2.21, U2.28, U2.37, U2.41, U3.3, U4.2, U5.1, U5.34, U5.44, U5.47, U6.1, U6.2, U6.9
unnamed: C1.2, P1.2
unnamed: C2.2, P1.3
unnamed: C3.2, P1.4
unnamed: C4.2, P1.5
unnamed: C5.1, U2.36
unnamed: C5.2, U2.38
unnamed: C11.1, U2.35
unnamed: C14.1, U2.22
unnamed: C15.1, U2.24
unnamed: C15.2, J2.2, R15.2
unnamed: C16.1, U2.25
unnamed: C16.2, J2.3, R18.1
unnamed: C20.2, MIC1.1
unnamed: C21.2, MIC2.1
unnamed: C23.2, R21.1, R23.2
unnamed: C24.2, R22.1, R24.2
unnamed: D1.1, R1.1
unnamed: D1.4, R11.1
unnamed: D2.2, R19.2
unnamed: D3.2, R20.2
unnamed: D4.2, R26.2
unnamed: D4.3, R27.2
unnamed: D4.4, R28.2
unnamed: IC1.14, R23.1
unnamed: IC1.16, R24.1
unnamed: R1.2, R11.2, U1.1
unnamed: R3.2, U2.3
unnamed: R4.2, U2.6
unnamed: R5.2, U2.7
unnamed: R6.2, U2.8
unnamed: R7.2, U2.9
unnamed: R8.2, U2.5
unnamed: R9.2, U2.14
unnamed: R10.2, U2.13
unnamed: R12.1, U1.5
unnamed: R18.2, U3.2

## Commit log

2020-01-31 Initial commit of schematics
    Basic copy paste of Tympan Rev D peripherals and power supply
    Needs Teensy 4 pin assignments
    [Tympan_Rev_E.kicad_pcb, Tympan_Rev_E.sch, file5E34A24A.sch]
2020-02-01 First Draft Schematics for Rev E
    [Tympan_Rev_E.sch, file5E34A24A.sch]
2020-02-01 updated with some notes on schem
    [Tympan_Rev_E.sch]
2020-02-03 Added notes
    [Tympan_Rev_E.sch]
2020-08-03 Teensy 4.1
    Removed SD card
    I2C connections per Chip's recommendation
    [Tympan_Rev_E.sch]
2020-08-21 Starting board layout
    [Tympan_Rev_E.sch]
2020-08-22 draft layout of parts
    [Tympan_Rev_E.kicad_pcb, Tympan_Rev_E.sch]
2020-08-26 Component layout ready for routing
    [Tympan_Rev_E.kicad_pcb]
2020-09-02 Tracks Layout and Zone Fill
    Passing DRC with minor courtyard flags. Needs touchup of tracks and silk.
    [Tympan_Rev_E.kicad_pcb, Tympan_Rev_E.sch]
2020-09-03 updated silk
    tidied up tracks and updated silk. Moved fuse from bottom to top, now only parts on bottom are teensy and microphones.
    [Tympan_Rev_E.kicad_pcb]
2020-09-08 Added pullup on BT reset pin and rout for battery cable
    [Tympan_Rev_E.kicad_pcb, Tympan_Rev_E.sch]
2020-09-29 Re routing and adding gas guage
    added gas guage and routed fuse per design rec in issue #6
    added pullups to the I2C2 lines
    cleaned silk and copper pours
    [Tympan_Rev_E.kicad_pcb, Tympan_Rev_E.sch]
2020-09-29 Added header for headphone connections
    [Tympan_Rev_E.kicad_pcb, Tympan_Rev_E.sch]
2020-10-05 UPDATED SCHEMATICS PDF
    [Tympan_Rev_E.sch]
2020-10-05 tweaked the copper pours
    [Tympan_Rev_E.kicad_pcb]
2021-01-23 Added csv BOM and swapped PDM nets
    [Tympan_Rev_E.csv, Tympan_Rev_E.sch]
2021-02-05 updating readme
    [Tympan_Rev_E.kicad_pcb, Tympan_Rev_E.sch, Tympan_Rev_E_BOM.csv]
2021-04-26 Removed excess stuff
    [Tympan_Rev_E.csv, Tympan_Rev_E_BOM.csv]
2021-04-27 ADDED TEENSY 41 PINS TO MIMX SYMBOL
    Checked and double checked pin associations
    [Tympan_Rev_E.sch]
2021-05-03 Pinout Teensy and AIC symbol
    [Tympan_Rev_E.sch]
2021-05-04 fit things into the title block
    [Tympan_Rev_E.sch]
2021-05-04 added schematic pdf
2021-05-13 Made changes in Project.
    Check ReadMe for details on changes.
    [Tympan_Rev_E.csv, Tympan_Rev_E.kicad_pcb, Tympan_Rev_E.sch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]
2021-05-13 added PDF of schematics
    [Tympan_Rev_E.kicad_pcb]
2021-05-15 fixes to silk and delete unused tracks
    [Tympan_Rev_E.kicad_pcb]
2021-05-15 added a link to the Circuit Hub project
2021-05-17 moved ICP Shield header
    [Tympan_Rev_E.kicad_pcb, Tympan_Rev_E.sch]
2021-05-18 added 2 more breakouts
    [Tympan_Rev_E.kicad_pcb, Tympan_Rev_E.sch]
2021-05-18 update schematic pdf
2021-05-21 Added through hole prog button and Qwiic connector
    [Tympan_Rev_E.kicad_pcb, Tympan_Rev_E.sch]
2021-05-21 Verified Qwiic pin order
    [Tympan_Rev_E.kicad_pcb, Tympan_Rev_E.sch]
2021-05-24 Final Review
    Adjust silk and some internal traces.
    add net names to SMT headers for DFM and placement
    publish up to date PDF
    [Tympan_Rev_E.kicad_pcb, Tympan_Rev_E.sch]
2021-05-24 Updated Silk
    added version and note next to Quiic/Stemma connector
    [Tympan_Rev_E.kicad_pcb, Tympan_Rev_E.sch]
2021-06-21 Enclosure CAD for Test Print
    [7146_Tympan_Rev-E2_Bottom_Case.STEP, 7146_Tympan_Rev-E2_Bottom_Case.STL, 7146_Tympan_Rev-E2_Top_Case.STEP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]
2021-06-23 Updated Rev-E2 Enclosure
    [7146_Tympan_Rev-E2_Bottom_Case.STEP, 7146_Tympan_Rev-E2_Bottom_Case.STL, 7146_Tympan_Rev-E2_Top_Case.STEP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]
2021-06-23 Corrected LED port alignment
    [7146_Tympan_Rev-E2_Bottom_Case.STEP, 7146_Tympan_Rev-E2_Top_Case.STEP]
2021-06-23 Added belt clip holes and revised lettering
    [7146_Tympan_Rev-E2_Bottom_Case.STEP, 7146_Tympan_Rev-E2_Top_Case.STEP]
2021-06-24 Updated Enclosure
    Adjusted heat set insert hole for belt clip
    Added space for label
    [7146_Tympan_Rev-E2_Bottom_Case.STEP, 7146_Tympan_Rev-E2_Top_Case.STEP]
2021-06-28 updates to the enclosure files
    I'm adding the mods that I made to the enclosure
    [7146_Tympan_Rev-E2_Bottom_Case.stl, 7146_Tympan_Rev-E2_Top_Case.stl, Tympan Rev E-2 BOTTOM_Flywheel_Mod.stl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]
2021-08-06 Added enclosure STLs
    Production STL files uploaded
    [7-21 Tympan Rev E-2 Bottom.stl, 7-21 Tympan Rev E-2 Top.stl]
2022-06-04 Added initial Blender model
    [Tympan_Rev_E.step]
2023-12-04 Files cleanup
    Removed older versions of the kicad files from previous kicad releases.
    [Tympan_Rev_E.csv, Tympan_Rev_E.kicad_pcb, Tympan_Rev_E.kicad_sch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]
